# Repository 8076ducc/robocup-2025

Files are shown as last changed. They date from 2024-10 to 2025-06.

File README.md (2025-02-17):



# ducc. Robotics: RoboCupJunior Soccer 2025

This repository contains ducc's working files and source code for the 2025 RoboCupJunior Soccer Open and Soccer Lightweight competition.

## About

ducc is a six-man team comprising **Neo Hao Jun, Isaac Tan, Zhu Yunsong, Aidan Yeong, Faith Yang and Neo Jun Hao** from the **Hwa Chong Robotics Club** in Singapore.

## Technologies

This project was built with the following tools:

- Mechanical: Autodesk Fusion
- Electrical: KiCad 7.0
- Programming: PlatformIO

## Intellectual Property

### Copyright

© 2025, ducc. Robotics Competition Team.

While we have made every effort to abide by legal and ethical requirements when using works that we did not create, some may have been overlooked inadvertently. Please let us know and we will be happy to make the necessary arrangements.

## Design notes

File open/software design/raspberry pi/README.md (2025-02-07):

1. Get the dt-blob-bin file by running `sudo wget https://datasheets.raspberrypi.com/cmio/dt-blob-dualcam.bin -O /boot/dt-blob.bin` in the terminal.

2. Run `sudo nano /boot/firmware/config.txt` in the terminal, scroll down and add the following lines to the bottom of the file:
```
dtoverlay=imx708,cam0
dtoverlay=imx708,cam1
```

3. Run `libcamera-hello` in the terminal to determine if the cameras are detected.

4. Compile OpenCV from source; follow the guide [here](https://qengineering.eu/install-opencv-on-raspberry-64-os.html).

5. Install LCCV by following the instructions [here](https://github.com/8076ducc/lccv).

6. Create symbolic links by running the following commands in the terminal:
```bash
sudo ln -s /usr/local/include/opencv4/opencv2 /usr/local/include/opencv2
sudo ln -s /usr/include/libcamera/libcamera /usr/local/include/libcamera
```

7. Install wiringpi by following the guide [here](https://github.com/WiringPi/WiringPi).

8. In Geany, manage your build settings and configure it to compile via the following command:
```bash
sudo g++ -Wall -o "%e" "%f" -lopencv_core -lopencv_videoio -lopencv_highgui -lopencv_imgproc -lopencv_video -llccv -lwiringPi
```

9. Test Geany compilation by pressing the brown brick button in your desired file (e.g. `tracker.cpp`; don't compile in `threads.h` or some other header file) THEN run the code by clicking the airplane symbol. You may wish to use the function row keyboard shortcuts at your convenience.

10. Transfer the two files in the `systemctl` folder in this repository to the `/lib/systemd/system` folder on the Raspberry Pi.

11. Ensure "enable_debug_windows" in threads.h is set to false.

12. Individually check that the services are working using the following commands:
```bash
sudo systemctl start configure-gpio.service
sudo systemctl status configure-gpio.service
sudo systemctl stop configure-gpio.service

sudo systemctl start tracker.service
sudo systemctl status tracker.service
sudo systemctl stop tracker.service
```

12. Enable both services to run on startup using the following commands:
```bash
sudo systemctl enable configure-gpio.service
sudo systemctl enable tracker.service
```

13. Run `sudo systemctl disable NetworkManager-wait-online.service` in the terminal.

Other notes:
- DO NOT 千万不要 plug or unplug the camera module while power is still connected. Shut the RPi down and unplug all power cables before doing anything with the camera module.
- Placing everything in the Desktop is a personal decision I made so that it's more convenient for me to open files when I VNC into the RPi. You might want to pull the entire repository directly into the RPi (I highly recomend that); in which case you should change the directories to the executables in the `configure-gpio.service` and `tracker.service` files.

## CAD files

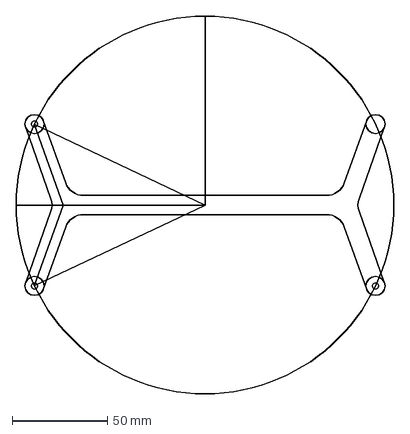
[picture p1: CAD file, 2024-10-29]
lightweight/lw handle.dxf
198.0 x 198.0 mm

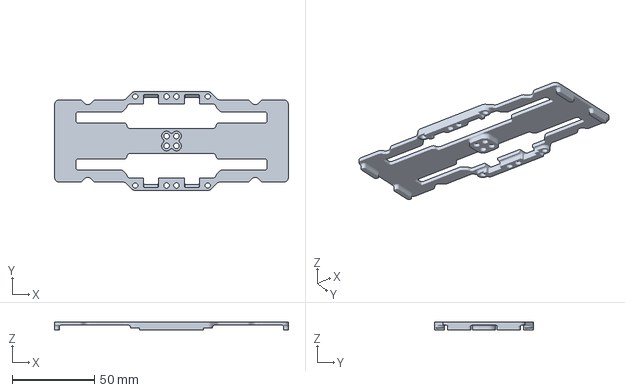
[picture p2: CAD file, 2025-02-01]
open/mechanical design/battery/driver cover (battery anti-short).3mf
142.0 x 60.0 x 5.00 mm

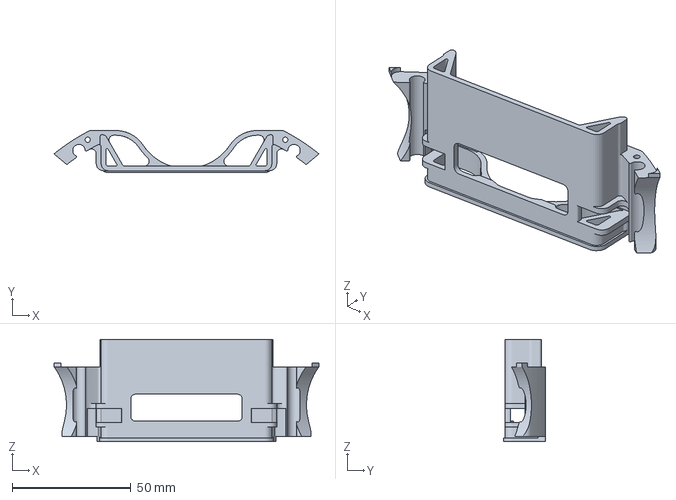
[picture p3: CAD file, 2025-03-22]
open/mechanical design/cover/layer 1/cover front (layer 1).3mf
111.8 x 17.7 x 43.2 mm

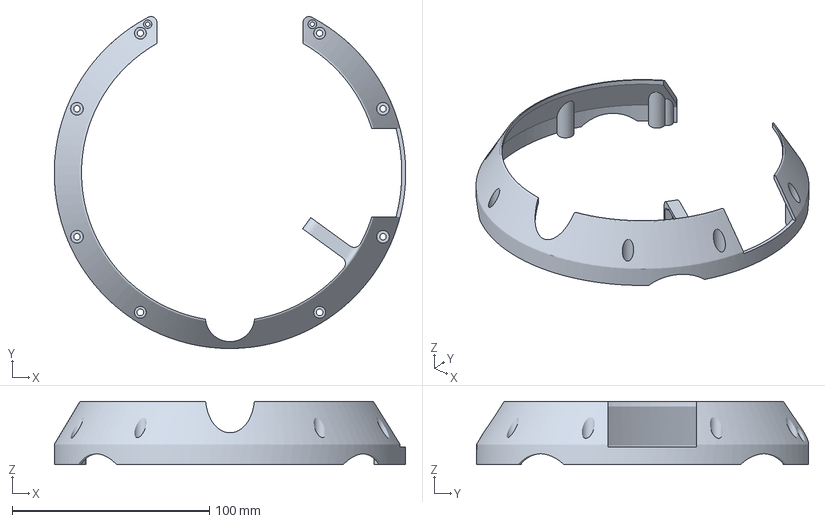
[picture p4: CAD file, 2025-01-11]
open/mechanical design/cover/layer 2/cover (layer 2).3mf
178.0 x 168.1 x 32.0 mm

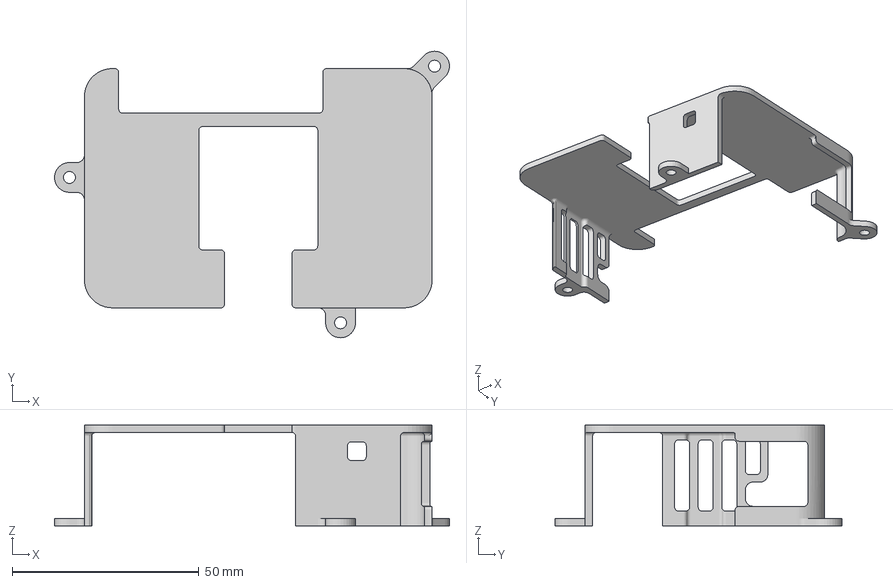
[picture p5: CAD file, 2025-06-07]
open/mechanical design/cover/layer 3/rpi cover.3mf
105.6 x 76.6 x 27.0 mm

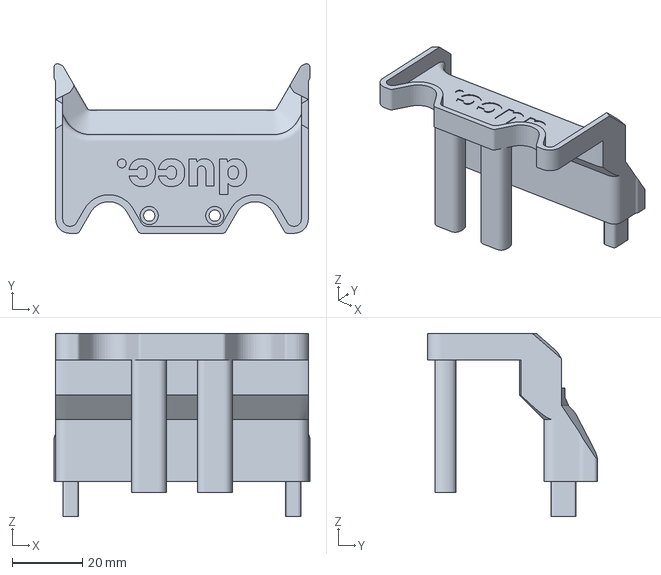
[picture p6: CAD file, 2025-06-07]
open/mechanical design/cover/servo/cover (servo).3mf
73.0 x 48.4 x 52.2 mm

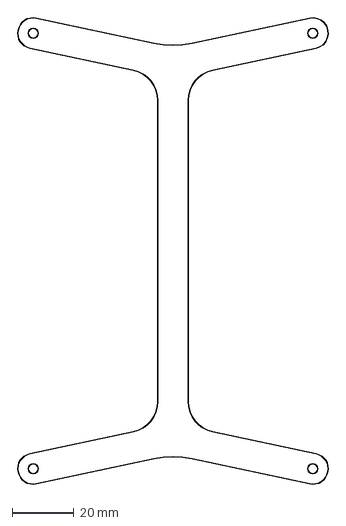
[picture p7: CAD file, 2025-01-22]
open/mechanical design/handle/handle.dxf
101.7 x 152.3 mm

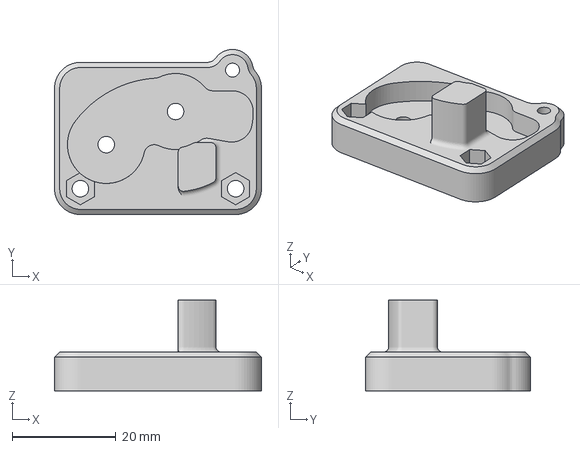
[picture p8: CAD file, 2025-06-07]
open/mechanical design/kicker/ratchet gear mount.3mf
40.0 x 31.9 x 17.5 mm

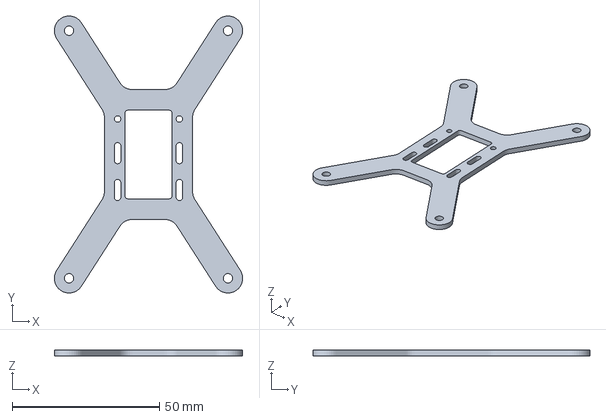
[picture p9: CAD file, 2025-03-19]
open/mechanical design/layer 4/layer 4 (new).3mf
64.0 x 94.2 x 2.00 mm

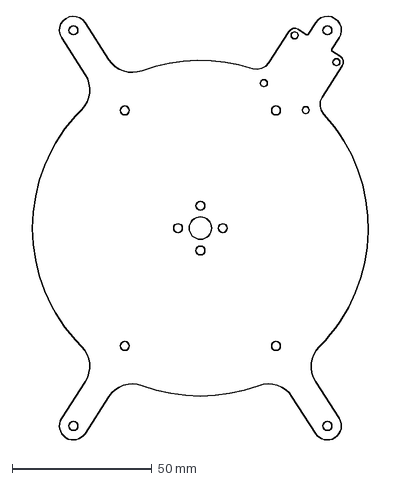
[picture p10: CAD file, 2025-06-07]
open/mechanical design/layer 5/layer 5 (no pin holes).dxf
131.8 x 152.2 mm

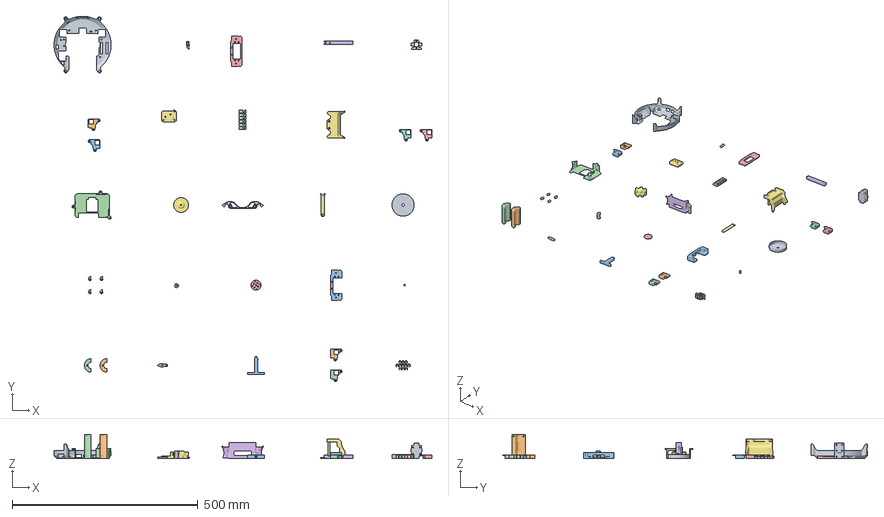
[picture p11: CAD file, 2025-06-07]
open/mechanical design/master.3mf
1018.0 x 984.3 x 65.0 mm
cover (layer 3)
buck cover left x 3
gear rack
buck cover right x 3
cover (servo)
rack
filament roller right
servo mount x 2
filament roller left
ratchet wheel
pawl x 4
wheel
ratchet
rpi cover
slide
ratchet gear mount
buck spacer x 6
cover front (layer 1)
m2.5 wrench
bearing spacer
mirror sawing plate
ratchet (new)
wire clip x 11

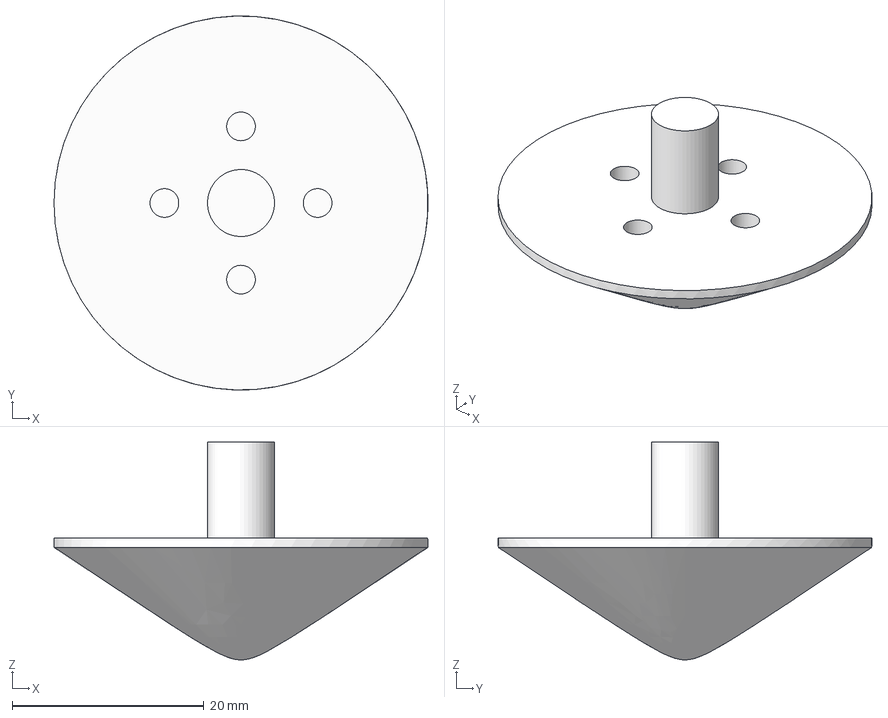
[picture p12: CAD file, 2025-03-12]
open/mechanical design/mirror/mirror with extrusion.step
39.1 x 39.0 x 22.7 mm

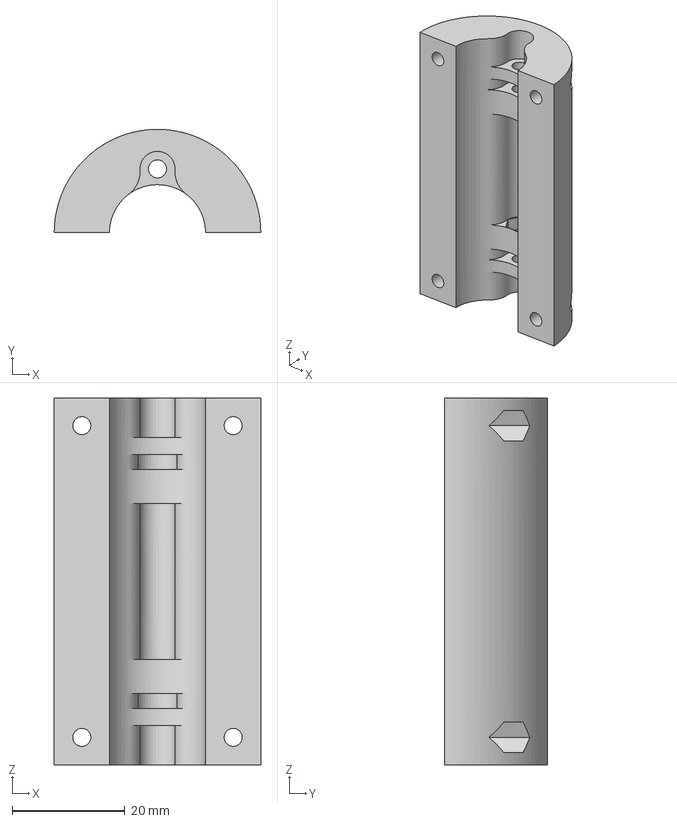
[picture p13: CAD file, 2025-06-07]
open/mechanical design/misc/filament roller left.3mf
36.6 x 18.3 x 65.0 mm

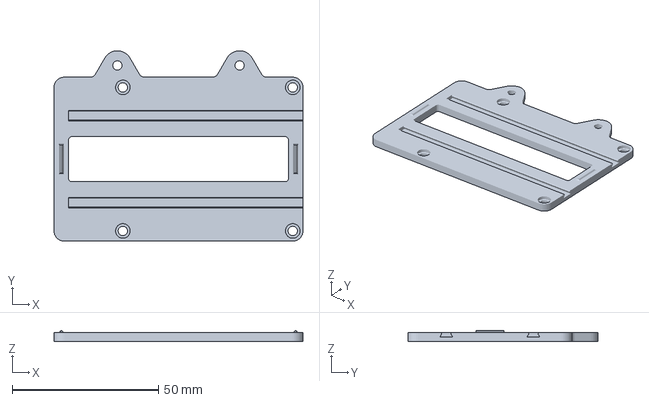
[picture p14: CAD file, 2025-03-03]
open/mechanical design/rpi & camera/base a/rpi mount base a upper.3mf
85.0 x 65.0 x 3.65 mm

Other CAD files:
open/mechanical design/rpi & camera/lens aligner.3mf
open/mechanical design/rpi & camera/nano b/rpi mount nano b.3mf
open/mechanical design/spinning kicker/left plate.3mf
open/mechanical design/wheel/4mm/wheel.3mf
open/mechanical design/battery/battery guide wall.3mf
open/mechanical design/cover/layer 1/cover back (layer 1).3mf
open/mechanical design/cover/layer 1/cover left (layer 1).3mf
open/mechanical design/cover/layer 1/cover right (layer 1).3mf
open/mechanical design/cover/layer 1/old/cover back (layer 1).stl
open/mechanical design/cover/layer 1/old/cover front left (layer 1) - old.stl
open/mechanical design/cover/layer 1/old/cover front left (layer 1).stl
open/mechanical design/cover/layer 1/old/cover front right (layer 1).stl
open/mechanical design/cover/layer 1/old/cover left (layer 1).stl
open/mechanical design/cover/layer 1/old/cover right (layer 1).stl
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

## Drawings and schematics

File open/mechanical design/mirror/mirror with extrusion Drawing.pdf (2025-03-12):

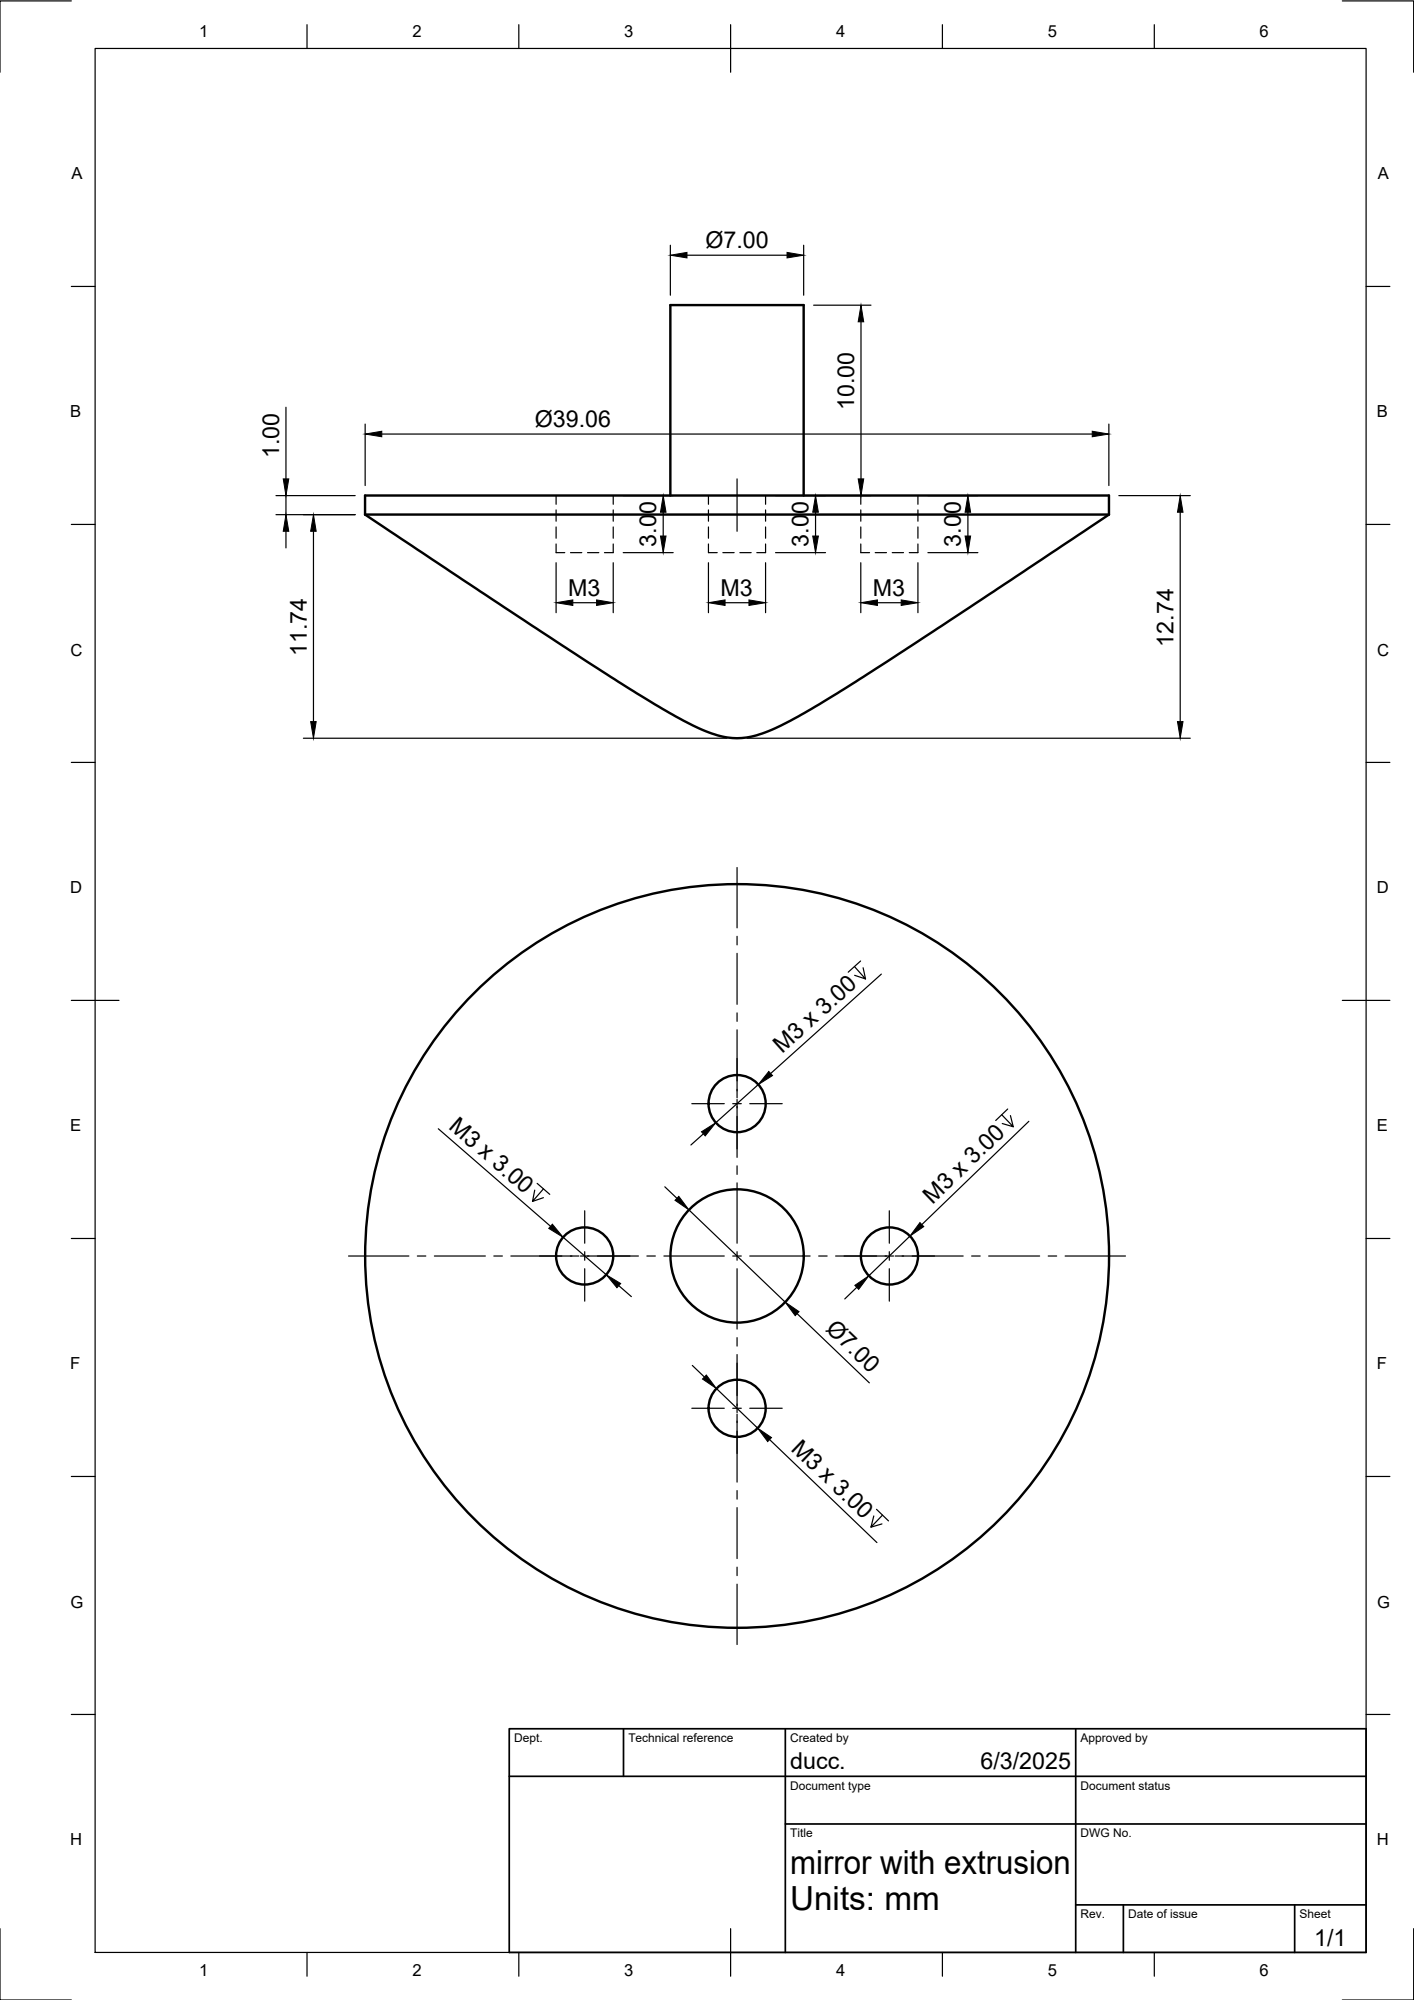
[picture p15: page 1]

Dept. | Technical reference | Created by ducc. 6/3/2025 | Approved by

Document type | Document status

Title mirror with extrusion Units: mm | DWG No.

Rev. | Date of issue | Sheet 1/1

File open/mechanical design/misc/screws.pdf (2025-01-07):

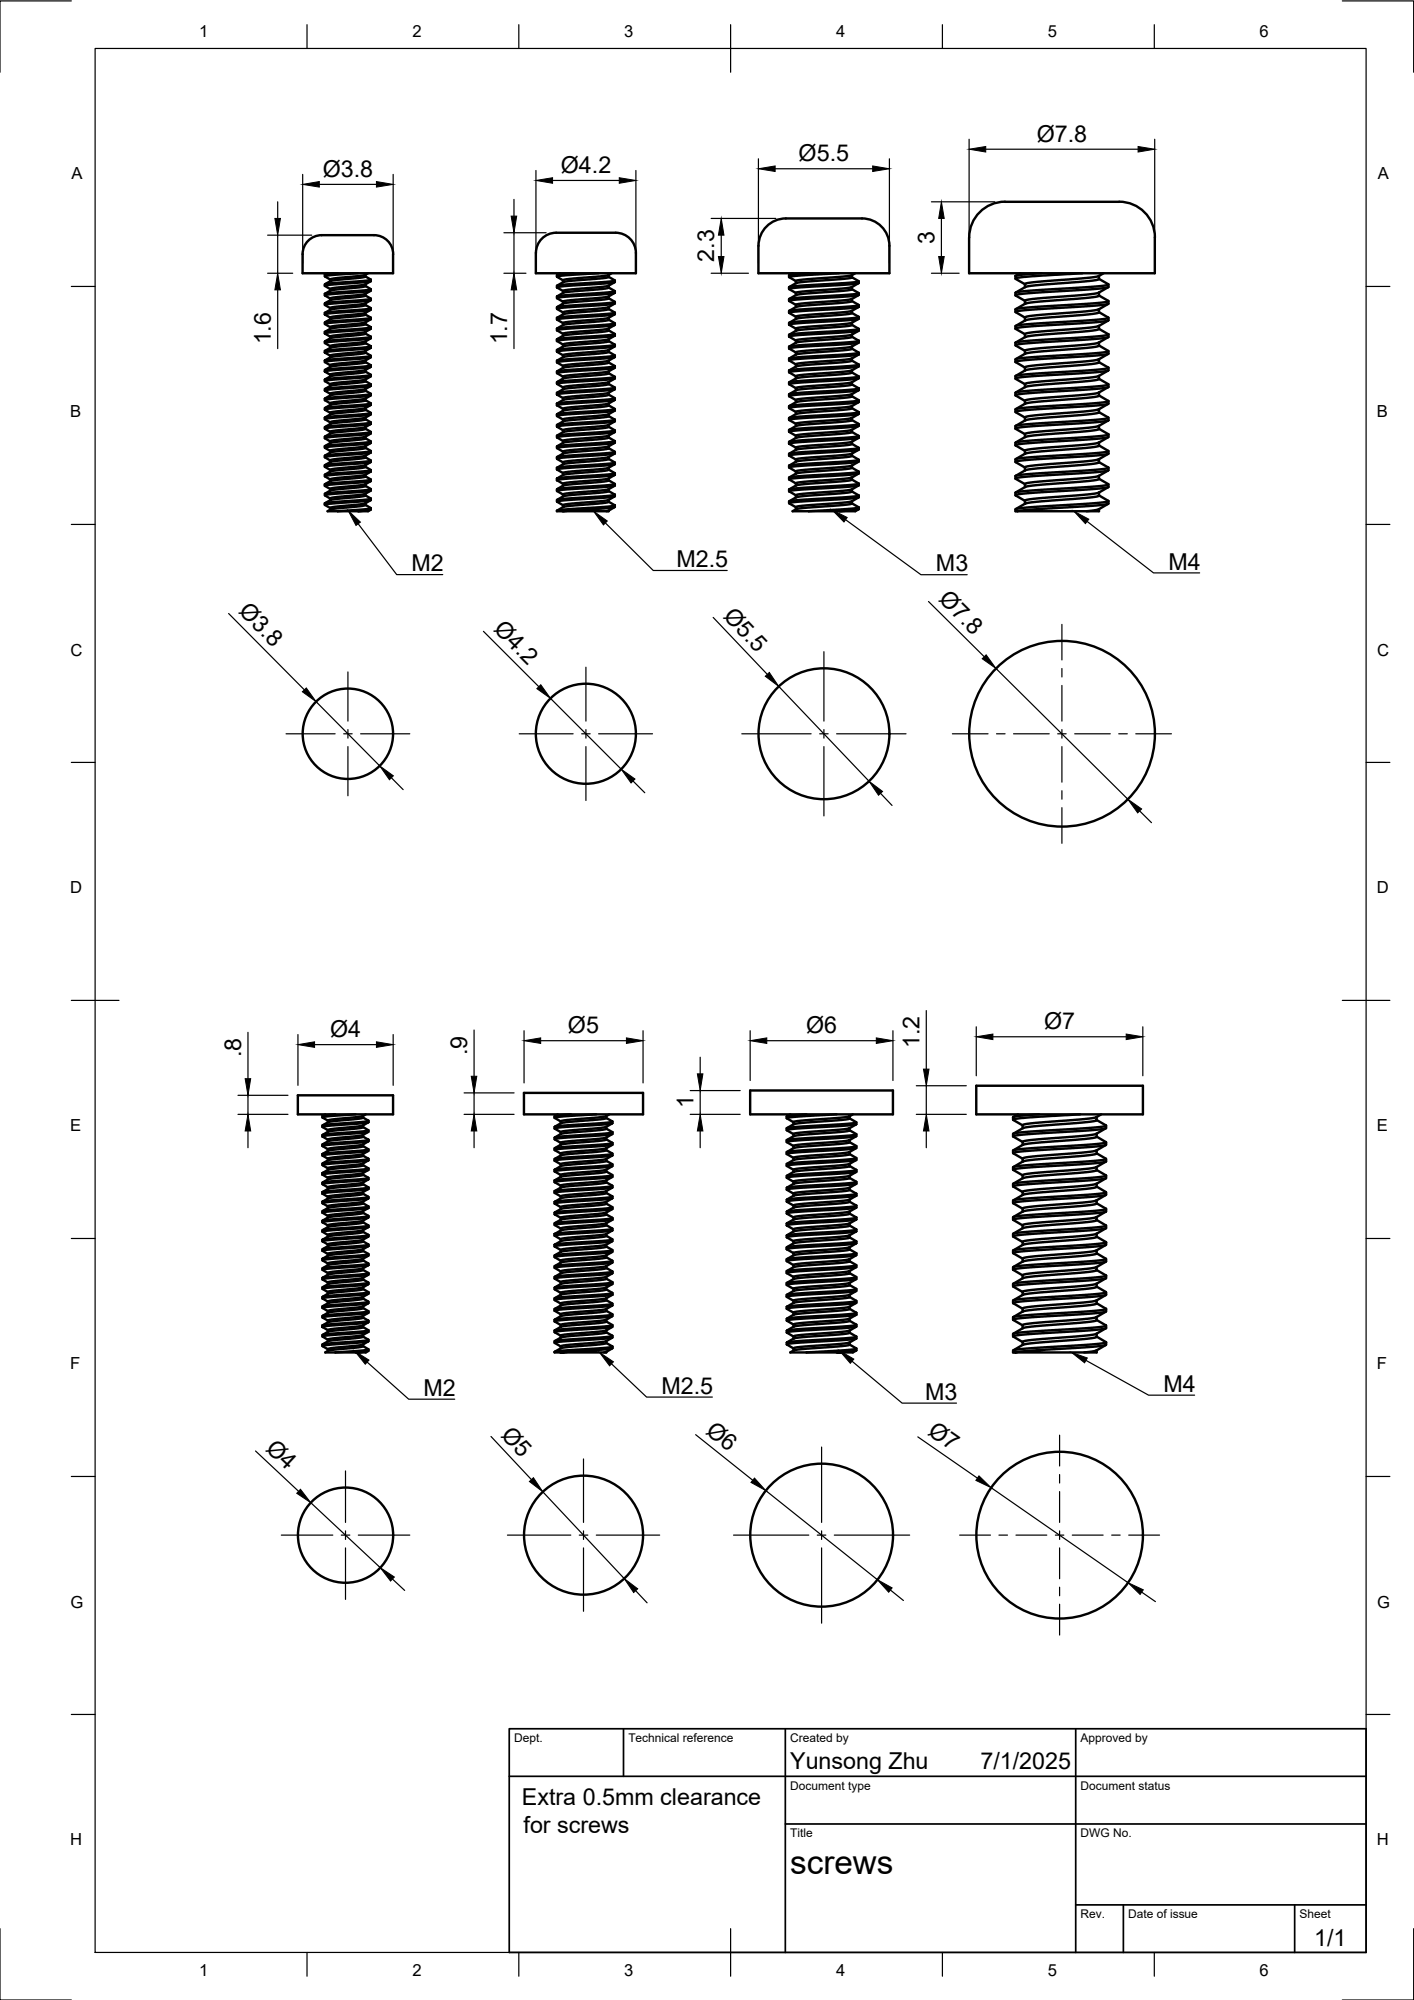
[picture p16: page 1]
for screws .8

Dept. | Technical reference | Created by Yunsong Zhu 7/1/2025 | Approved by

Extra 0.5mm clearance | | Document type | Document status

Title screws | DWG No.

Rev. | Date of issue | Sheet 1/1

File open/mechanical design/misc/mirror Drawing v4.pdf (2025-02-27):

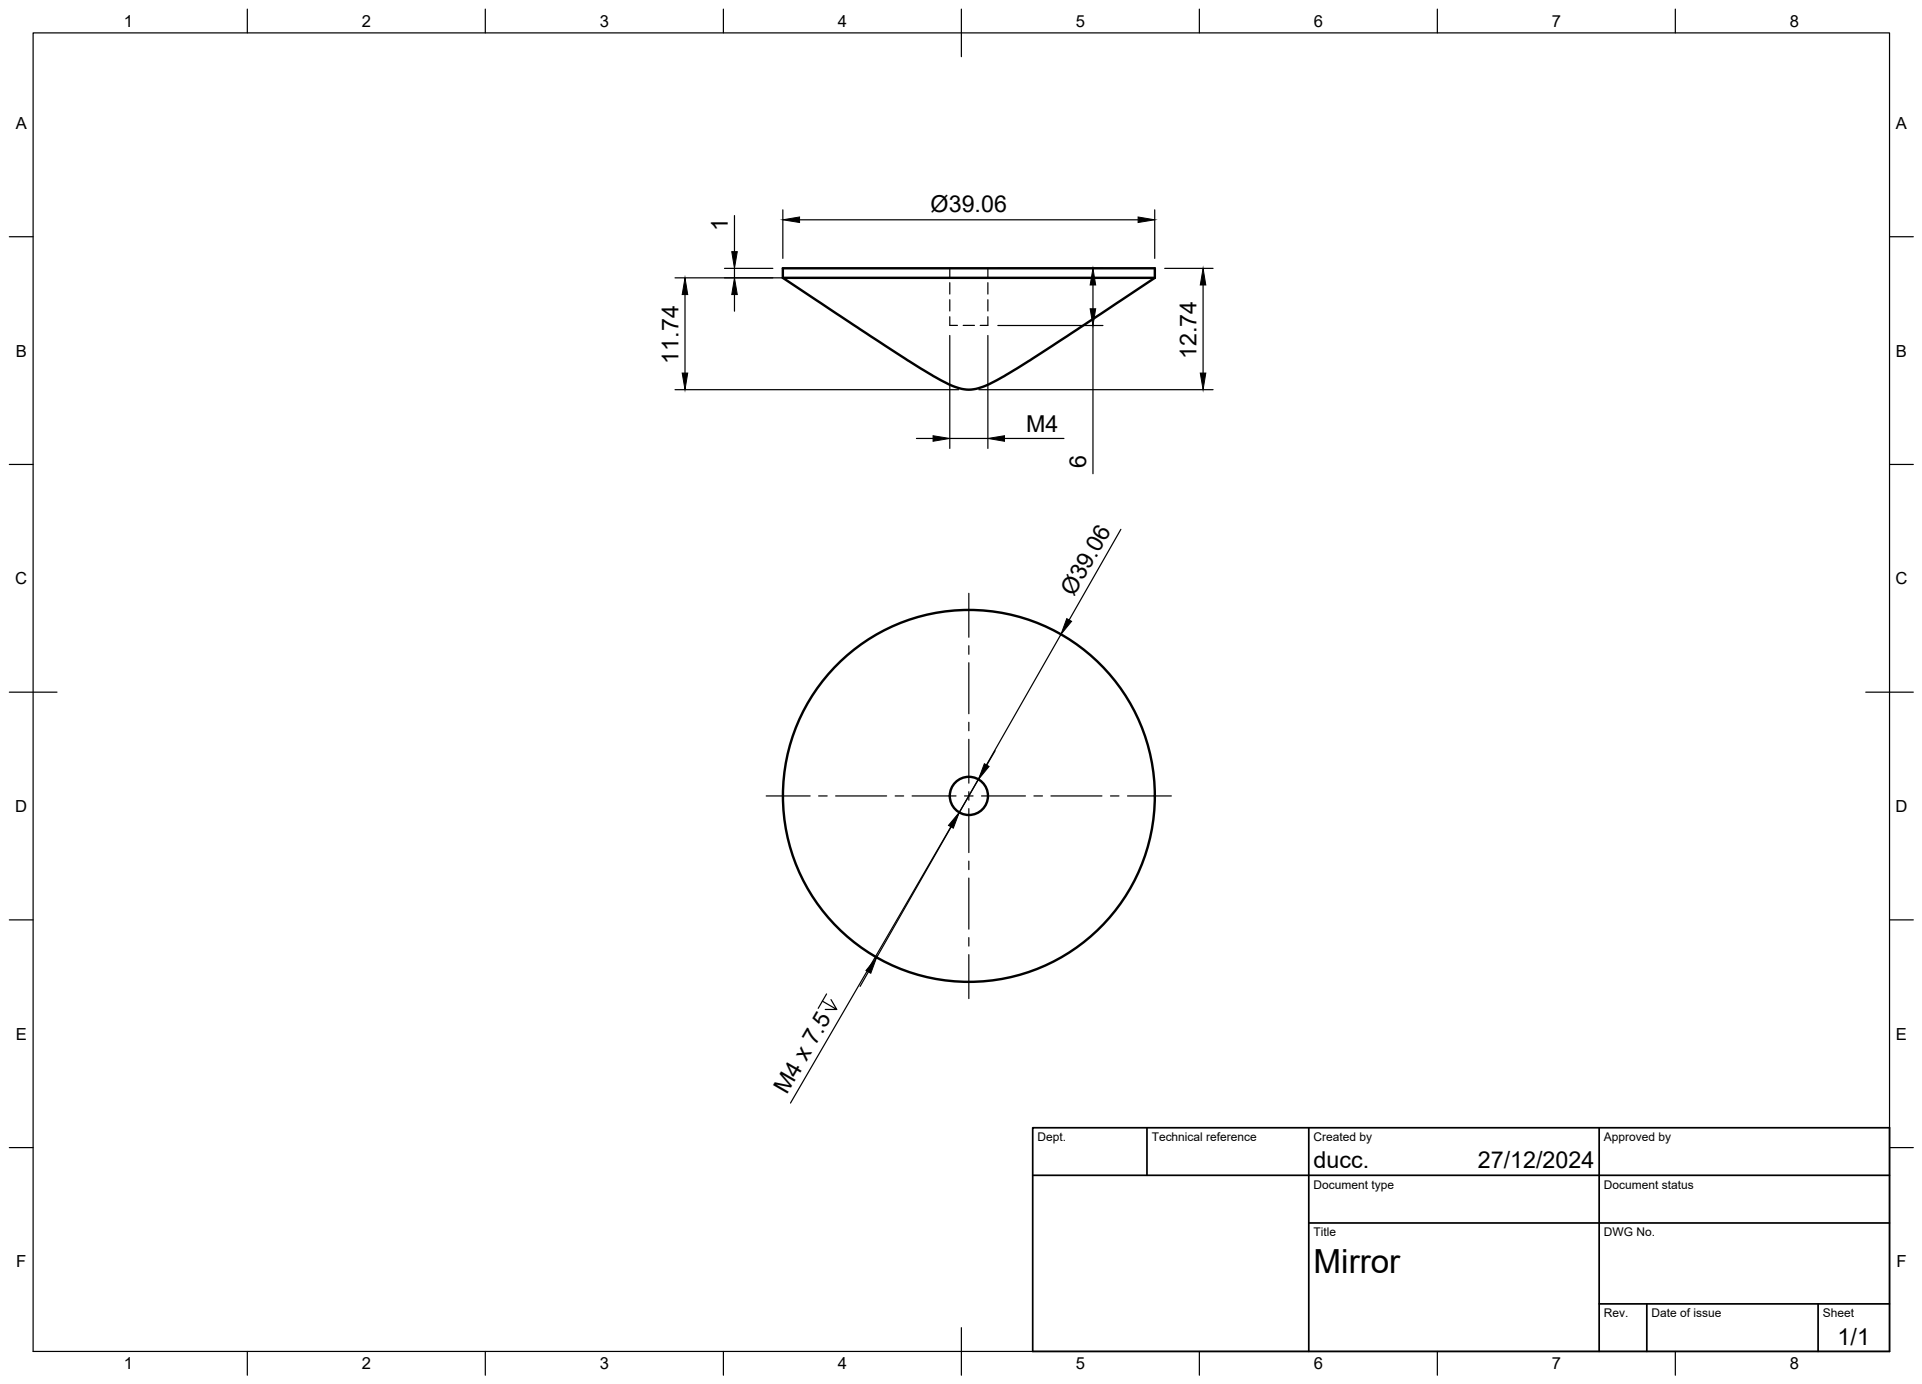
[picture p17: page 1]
Title; DWG No.; Rev.; Date of issue; Sheet

Dept. | Technical reference | Created by ducc. 27/12/2024 | Approved by

Document type | Document status

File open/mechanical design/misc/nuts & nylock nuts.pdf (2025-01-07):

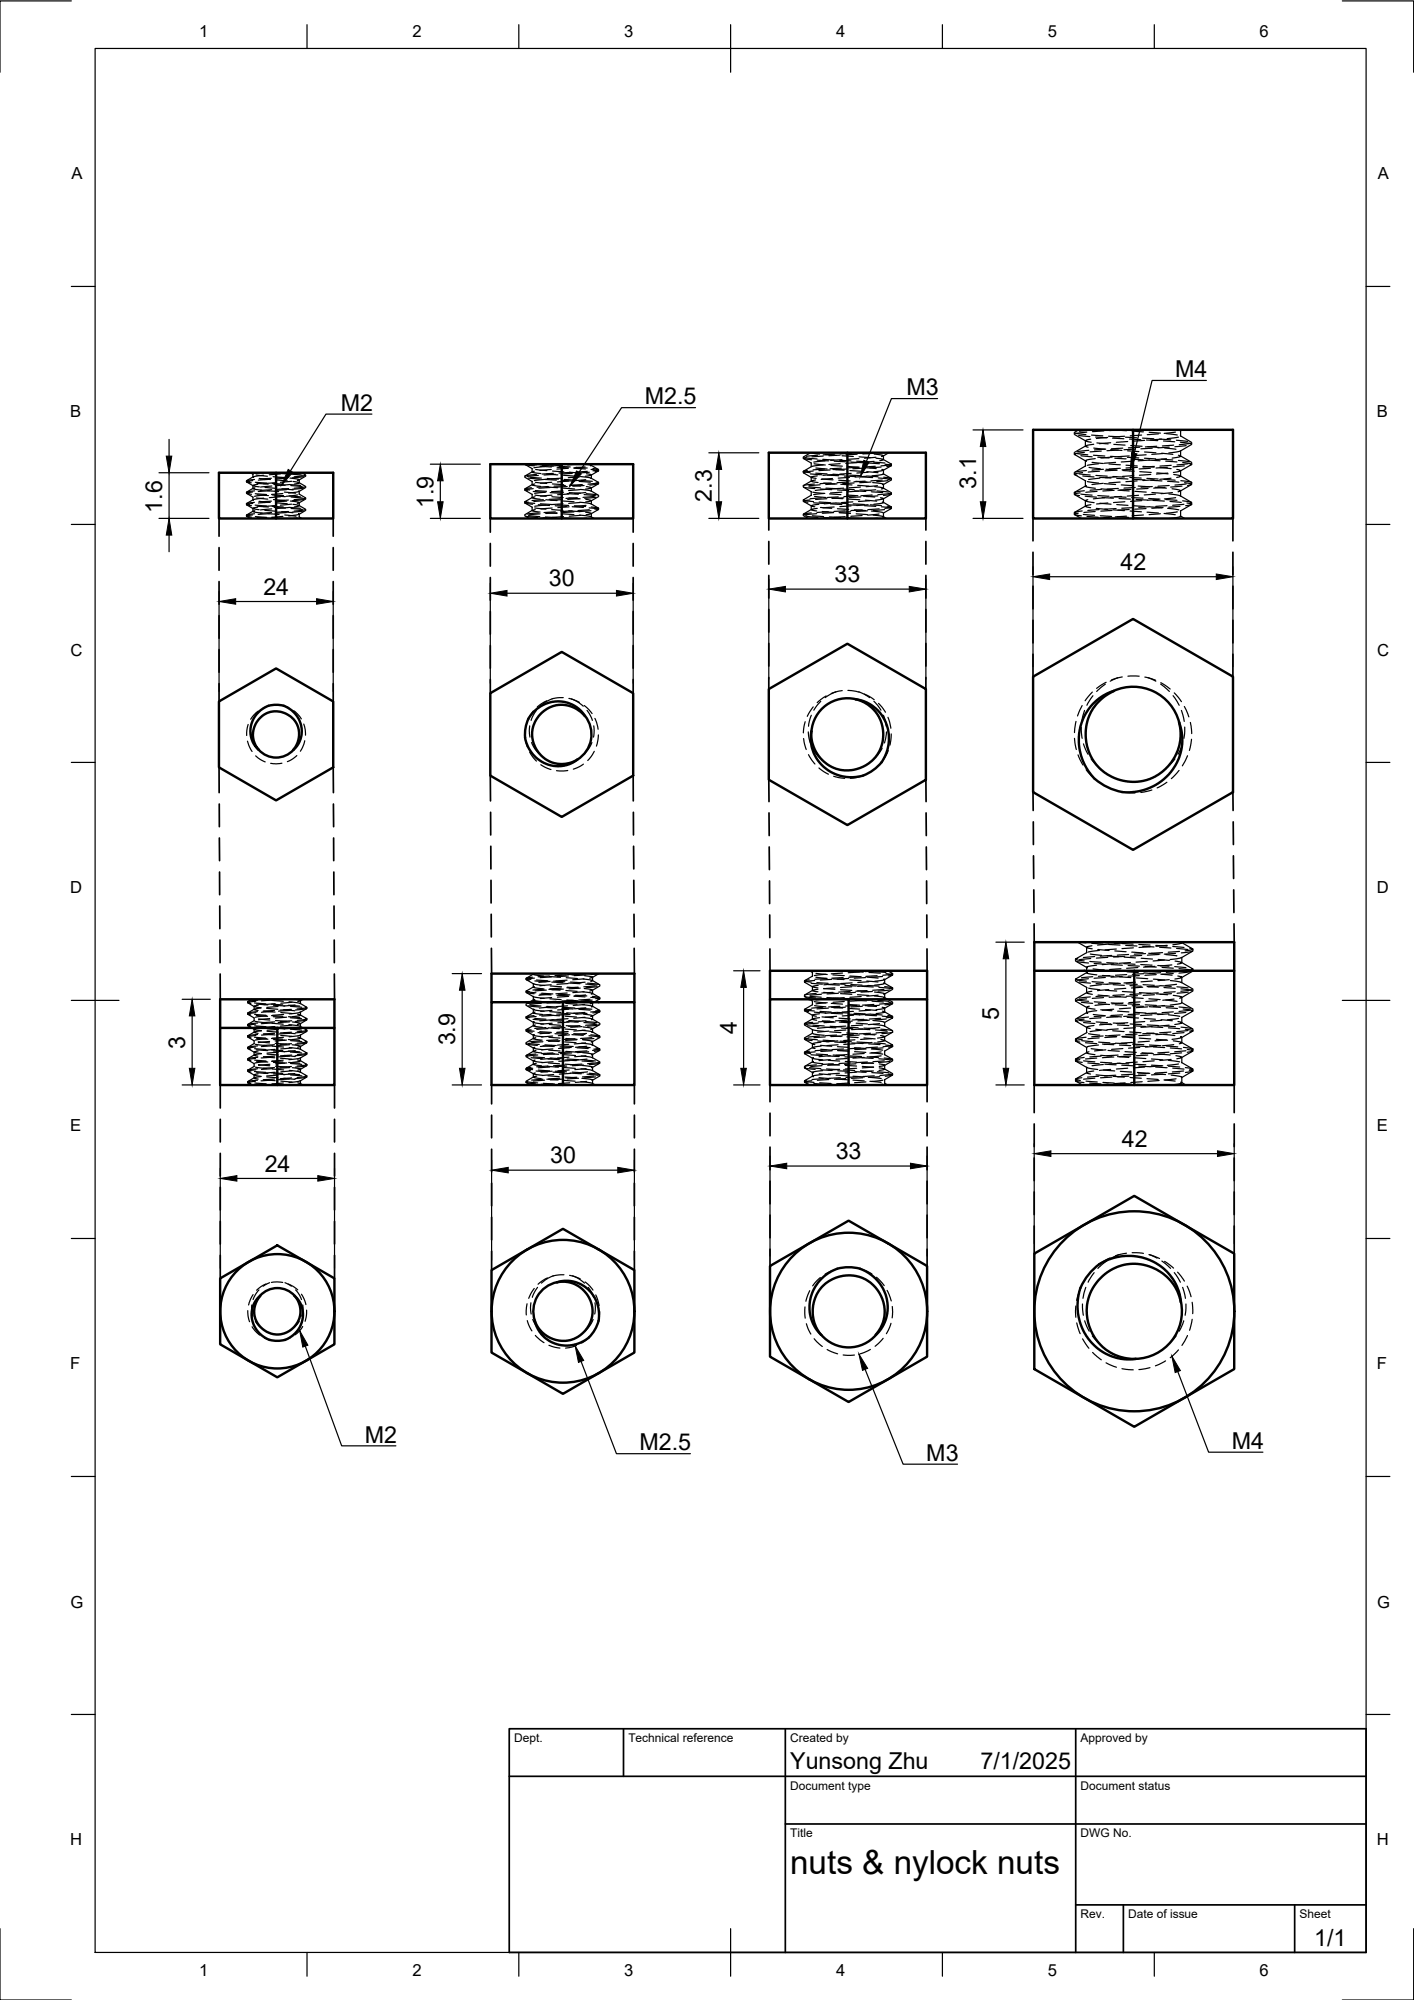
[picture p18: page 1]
Yunsong Zhu 1.6

Dept. | Technical reference | Created by 7/1/2025 | Approved by

Document type | Document status

Title nuts & nylock nuts | DWG No.

Rev. | Date of issue | Sheet 1/1

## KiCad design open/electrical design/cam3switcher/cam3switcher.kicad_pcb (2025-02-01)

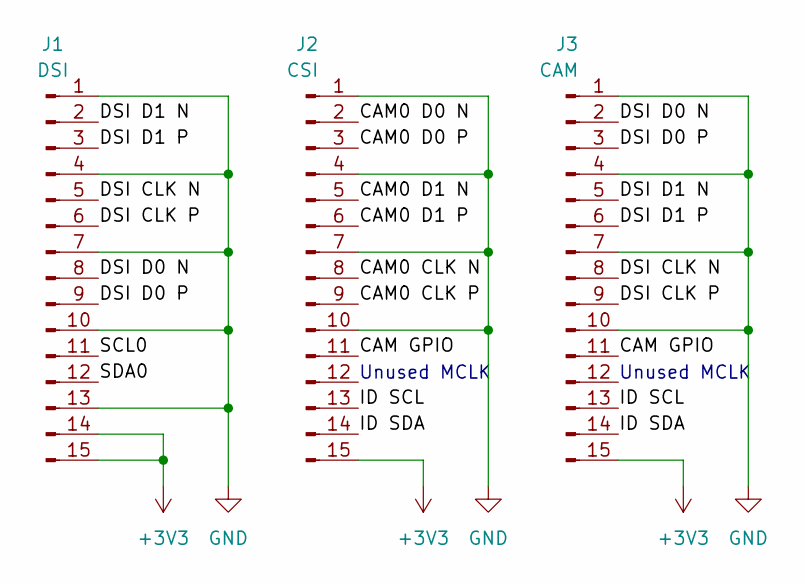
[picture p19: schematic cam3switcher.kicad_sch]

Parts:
J1: DSI; TE_1-84952-5_1x15-1MP_P1.0mm_Horizontal
J2: CSI; TE_1-84952-5_1x15-1MP_P1.0mm_Horizontal
J3: CAM; TE_1-84952-5_1x15-1MP_P1.0mm_Horizontal

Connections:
+3V3: J1.14, J1.15, J2.15, J3.15
/CAM0 CLK N: J2.8
/CAM0 CLK P: J2.9
/CAM0 D0 N: J2.2
/CAM0 D0 P: J2.3
/CAM0 D1 N: J2.5
/CAM0 D1 P: J2.6
/CAM GPIO: J2.11, J3.11
/DSI CLK N: J1.5, J3.8
/DSI CLK P: J1.6, J3.9
/DSI D0 N: J1.8, J3.2
/DSI D0 P: J1.9, J3.3
/DSI D1 N: J1.2, J3.5
/DSI D1 P: J1.3, J3.6
/ID SCL: J2.13, J3.13
/ID SDA: J2.14, J3.14
/SCL0: J1.11
/SDA0: J1.12
GND: J1.1, J1.4, J1.7, J1.10, J1.13, J2.1, J2.4, J2.7, J2.10, J3.1, J3.4, J3.7, J3.10

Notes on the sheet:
Unused MCLK

Board: 2 copper layers, 3 parts (0 on the bottom side), 11 nets, no tracks yet.

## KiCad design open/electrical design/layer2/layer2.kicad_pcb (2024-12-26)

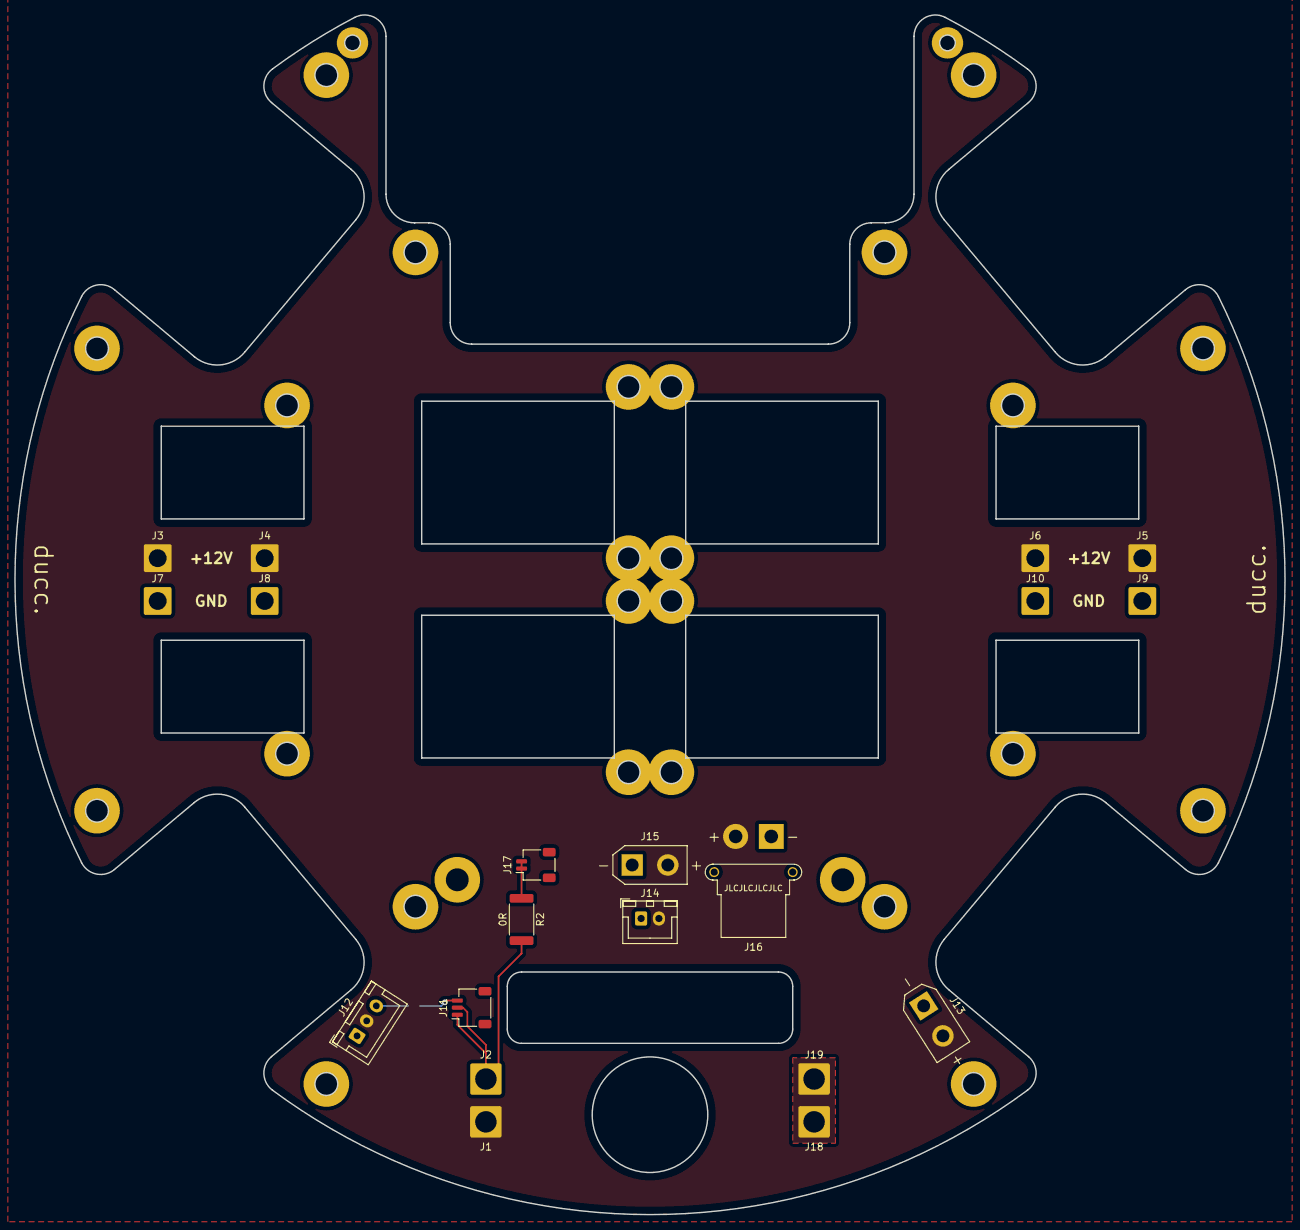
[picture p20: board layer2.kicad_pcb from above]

Board: 2 copper layers, 178.0 x 168.1 mm, 49 parts (1 on the bottom side), 6 nets.

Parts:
H1, H2, H3, H4, H5, H6, H7, H8, H9, H10, H11, H12, H13, H14, H15, H16, H17, H18, H19, H20, H21, H22, H23, H24, H25, H26: MountingHole; MountingHole_3.2mm_M3_Pad
H33, H34: MountingHole; MountingHole_2.2mm_M2_Pad
J1, J2, J18, J19: Conn_01x01_Female; SolderWire-2.5sqmm_1x01_D2.4mm_OD4.4mm
J3, J4, J5, J6, J7, J8, J9, J10: Conn_01x01_Female; SolderWire-2sqmm_1x01_D2mm_OD3.9mm
J11: SH1.0 3P; JST_SH_SM03B-SRSS-TB_1x03-1MP_P1.00mm_Horizontal
J12: XH2.54 3P; JST_XH_B3B-XH-A_1x03_P2.50mm_Vertical
J13, J15: XT30UPB-F; AMASS_XT30UPB-F_1x02_P5.0mm_Vertical
J14: XH2.54 2P; JST_XH_B2B-XH-A_1x02_P2.50mm_Vertical
J16: XT30PW-F; AMASS_XT30PW-F_1x02_P2.50mm_Horizontal
J17: SH1.0 2P; JST_SH_SM02B-SRSS-TB_1x02-1MP_P1.00mm_Horizontal
R1: 10k; R_0603_1608Metric
R2: 0R; R_2512_6332Metric

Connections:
+3V3: J11.3, R1.2
+12V: J1.1, J3.1, J4.1, J5.1, J6.1, J12.2, J13.2, J14.2, J15.2, J16.2
/BATT: J18.1, J19.1
GND: J2.1, J7.1, J8.1, J9.1, J10.1, J11.1, J11.2, J12.1, J13.1, J14.1, J15.1, J16.1, R2.2
unnamed: J12.3, R1.1
unnamed: J17.1, J17.2, R2.1

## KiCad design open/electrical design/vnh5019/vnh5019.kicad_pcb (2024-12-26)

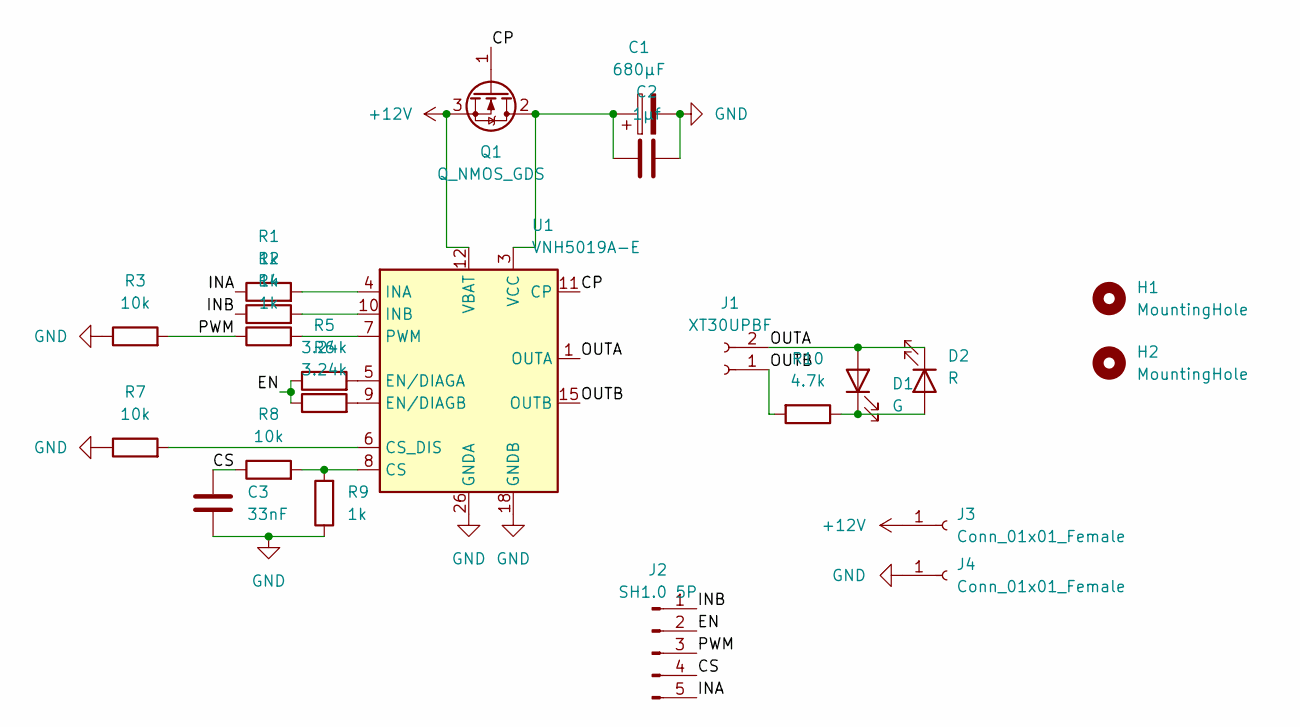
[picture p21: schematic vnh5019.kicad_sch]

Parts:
C1: 680µF; CP_Radial_D8.0mm_P3.50mm
C2: 1µf; C_0603_1608Metric
C3: 33nF; C_0603_1608Metric
D1: G; D_0603_1608Metric
D2: R; D_0603_1608Metric
H1, H2: MountingHole; MountingHole_3.2mm_M3_Pad
J1: XT30UPBF; AMASS_XT30UPB-F_1x02_P5.0mm_Vertical
J2: SH1.0 5P; JST_SH_SM05B-SRSS-TB_1x05-1MP_P1.00mm_Horizontal
J3, J4: Conn_01x01_Female; SolderWirePad_1x01_SMD_5x10mm
Q1: Q_NMOS_GDS; TO-252-2
R1, R2, R4, R9: 1k; R_0603_1608Metric
R3, R7, R8: 10k; R_0603_1608Metric
R5, R6: 3.24k; R_0603_1608Metric
R10: 4.7k; R_0603_1608Metric
U1: VNH5019A-E; ST_MultiPowerSO-30

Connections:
+12V: J3.1, Q1.3 (S), U1.12 (VBAT)
/CP: Q1.1 (G), U1.11 (CP)
/CS: C3.1, J2.4, R8.1
/EN: J2.2, R5.1, R6.1
/INA: J2.5, R1.1
/INB: J2.1, R2.1
/OUTA: D1.2 (A), D2.1 (K), J1.2, U1.1 (OUTA), U1.25 (OUTA), U1.30 (OUTA), U1.33 (OUTA)
/OUTB: J1.1, R10.2, U1.15 (OUTB), U1.16 (OUTB), U1.21 (OUTB), U1.32 (OUTB)
/PWM: J2.3, R3.2, R4.1
GND: C1.2, C2.2, C3.2, J4.1, R3.1, R7.1, R9.1, U1.18 (GNDB), U1.19 (GNDB), U1.20 (GNDB), U1.26 (GNDA), U1.27 (GNDA), U1.28 (GNDA)
unnamed: D1.1 (K), D2.2 (A), R10.1
unnamed: C1.1, C2.1, Q1.2 (D), U1.3 (VCC), U1.13 (VCC), U1.23 (VCC), U1.31 (VCC)
unnamed: R8.2, R9.2, U1.8 (CS)
unnamed: R7.2, U1.6 (CS_DIS)
unnamed: R5.2, U1.5 (EN/DIAGA)
unnamed: R6.2, U1.9 (EN/DIAGB)
unnamed: R1.2, U1.4 (INA)
unnamed: R2.2, U1.10 (INB)
unnamed: R4.2, U1.7 (PWM)

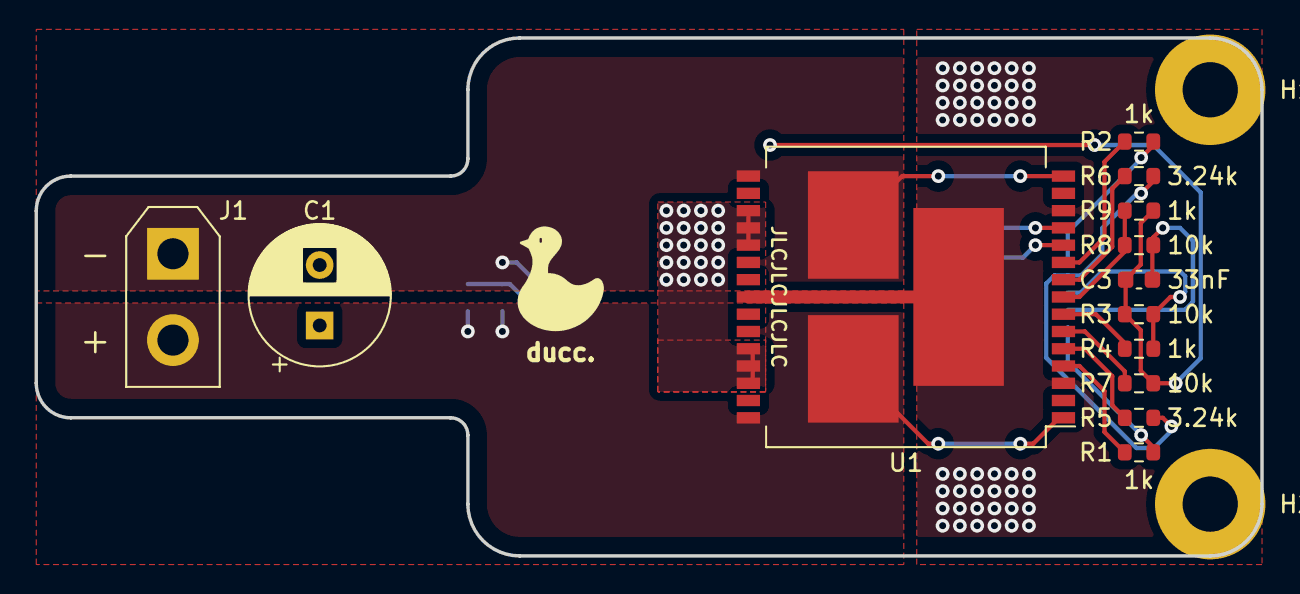
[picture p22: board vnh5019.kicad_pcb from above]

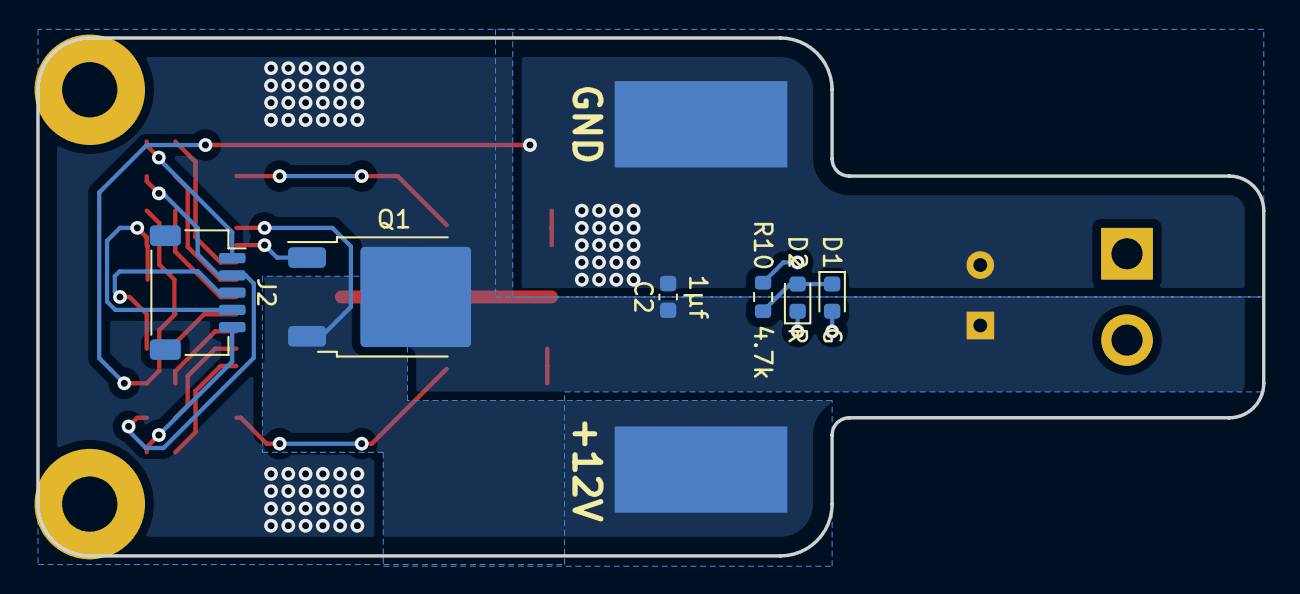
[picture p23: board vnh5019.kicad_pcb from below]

Board: 2 copper layers, 71.0 x 30.0 mm, 23 parts (8 on the bottom side), 19 nets.

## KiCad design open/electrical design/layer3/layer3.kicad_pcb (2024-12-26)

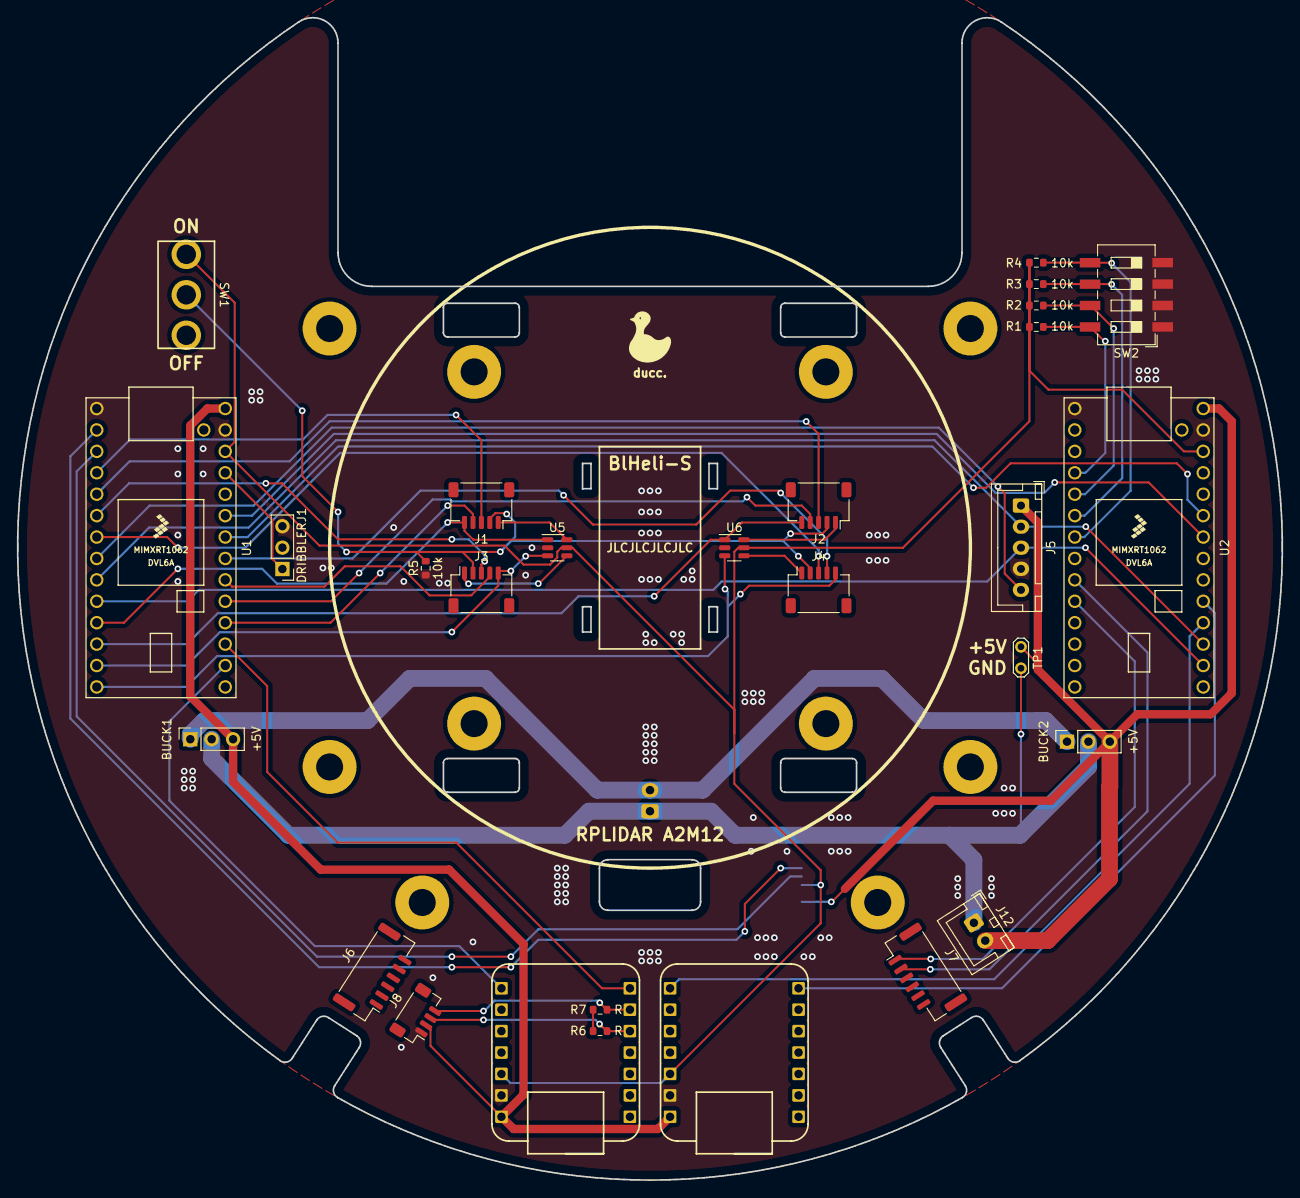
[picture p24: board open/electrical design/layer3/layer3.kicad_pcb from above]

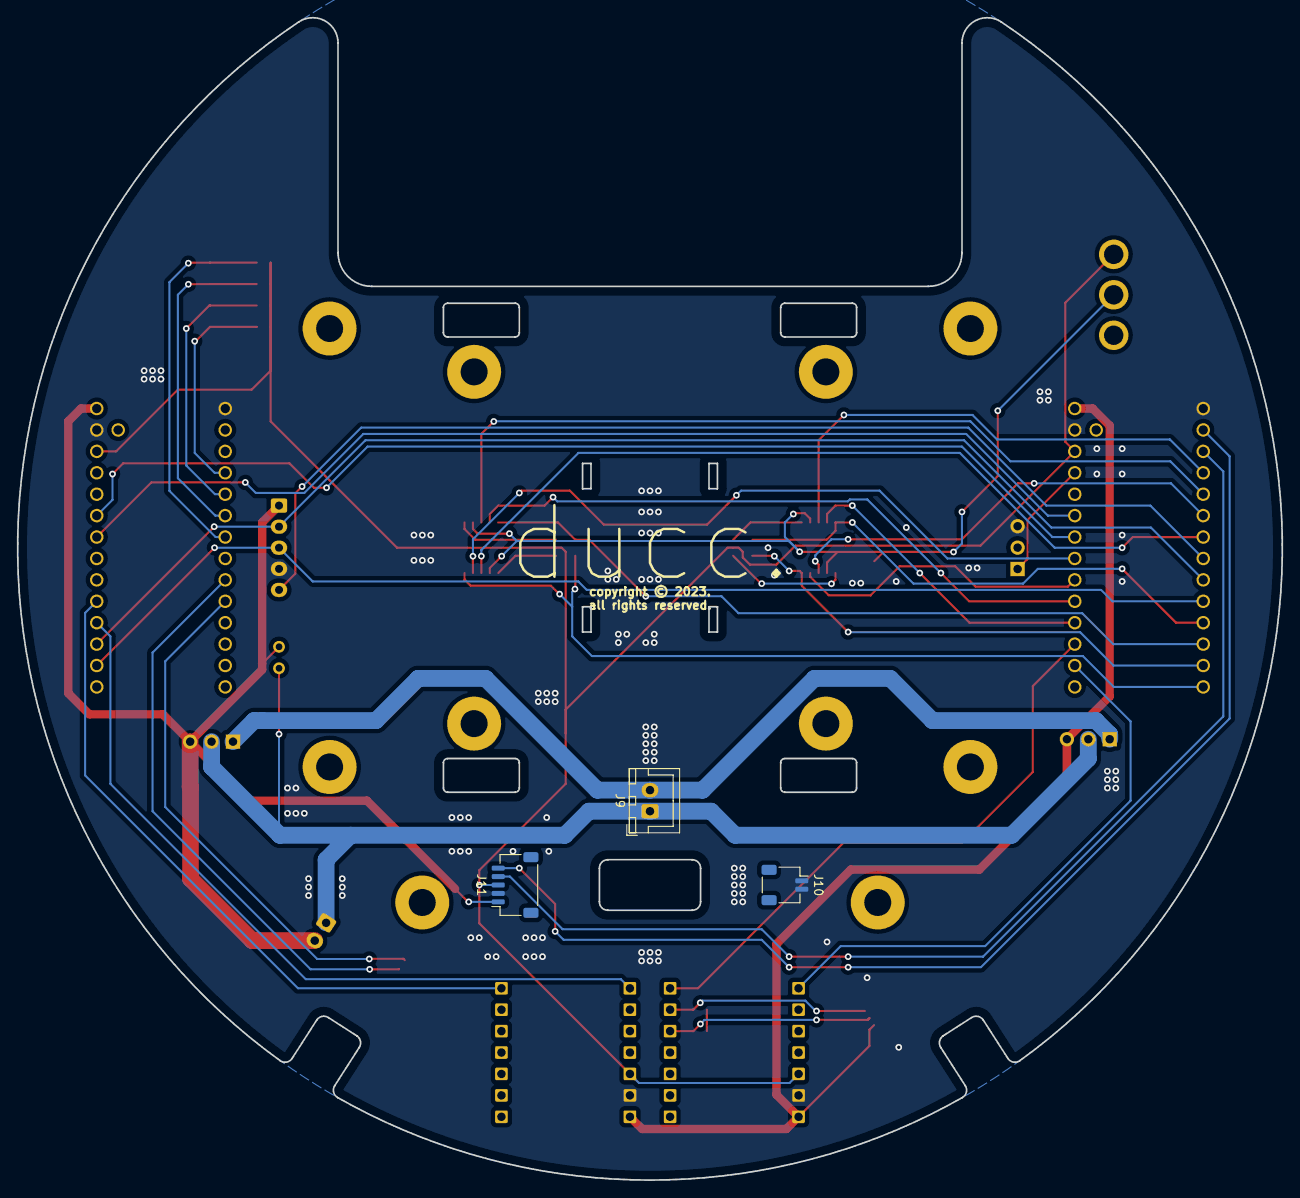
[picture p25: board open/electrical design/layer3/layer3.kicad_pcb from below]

Board: 2 copper layers, 150.0 x 137.9 mm, 41 parts (3 on the bottom side), 45 nets.

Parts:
BUCK1, BUCK2: +5V; TPS5430 Board
DRIBBLERJ1: Conn_01x03_Male; PinHeader_1x03_P2.54mm_Vertical
H1, H2, H3, H4, H5, H6, H7, H8, H9, H10: MountingHole; MountingHole_3.2mm_M3_Pad
J1, J2, J3, J4, J11: SH1.0 5P; JST_SH_SM05B-SRSS-TB_1x05-1MP_P1.00mm_Horizontal
J5: XH2.54 5P; JST_XH_B5B-XH-A_1x05_P2.50mm_Vertical
J6: CAMERA1; JST_GH_BM06B-GHS-TBT_1x06-1MP_P1.25mm_Vertical
J7: CAMERA2; JST_GH_BM06B-GHS-TBT_1x06-1MP_P1.25mm_Vertical
J8: COMPASS; JST_SH_BM04B-SRSS-TB_1x04-1MP_P1.00mm_Vertical
J9, J12: XH2.54 2P; JST_XH_B2B-XH-A_1x02_P2.50mm_Vertical
J10: SH1.0 2P; JST_SH_SM02B-SRSS-TB_1x02-1MP_P1.00mm_Horizontal
R1, R2, R3, R4, R5: 10k; R_0603_1608Metric
R6, R7: R; R_0603_1608Metric
SW1: SW_SPDT; SWITCH_SPDT_PTH_12.7X6.7MM
SW2: SW_DIP_x04; SW_DIP_SPSTx04_Slide_6.7x11.72mm_W8.61mm_P2.54mm_LowProfile
TP1: TestPoint_2Pole; TestPoint_2Pads_Pitch2.54mm_Drill0.8mm
U1, U2: TEENSY 4.0; Teensy40
U3, U4: MOUDLE-SEEEDUINO-XIAO-ESP32C3; xiao-esp32c3
U5, U6: 74LVC2G04; SOT-23-6

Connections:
+3V3: J11.3, R1.1, R2.1, R3.1, R4.1, SW1.1 (A), U1.3.3V_2, U2.3.3V_2, U3.12 (3V3), U4.12 (3V3), U5.5 (VCC), U6.5 (VCC)
+5V: BUCK1.3, BUCK2.3, J5.1, J8.2, J11.1, J12.2, TP1.1, U1.VIN, U2.VIN, U3.14 (5V), U4.14 (5V)
+12V: BUCK1.1, BUCK2.1, J9.2
/BTRX: U2.17, U4.7 (PB08_A6_D6_TX)
/BTTX: U2.16, U4.8 (PB09_A7_D7_RX)
/CAM1RX: J6.1, U2.1
/CAM1TX: J6.2, U2.0
/CAM2RX: J7.1, U2.8
/CAM2TX: J7.2, U2.7
/DRIBBLERPWM: DRIBBLERJ1.1, U1.23
/EN: J1.2, J2.2, J3.2, J4.2, R5.2, SW1.2 (B)
/IMURX: U1.14, U3.8 (PB09_A7_D7_RX)
/IMUSCL: J8.4, R7.1, U3.6 (PA9_A5_D5_SCL)
/IMUSDA: J8.3, R6.1, U3.5 (PA8_A4_D4_SDA)
/IMUTX: U1.15, U3.7 (PB08_A6_D6_TX)
/L1RX: J11.4, U1.1
/L1TX: J11.5, U1.0
/LIDARPWM: J5.5, U1.6
/LIDARRX: J5.3, U1.8, U2.14
/LIDARTX: J5.2, U1.7, U2.15
/M1CS: J1.4, U1.16
/M1INA: J1.5, U1.9, U5.1
/M1INB: J1.1, U5.6
/M1PWM: J1.3, U1.2
/M2CS: J2.4, U1.17
/M2INA: J2.5, U1.10, U6.1
/M2INB: J2.1, U6.6
/M2PWM: J2.3, U1.3
/M3CS: J3.4, U1.18
/M3INA: J3.5, U1.11, U5.3
/M3INB: J3.1, U5.4
/M3PWM: J3.3, U1.4
/M4CS: J4.4, U1.19
/M4INA: J4.5, U1.12, U6.3
/M4INB: J4.1, U6.4
/M4PWM: J4.3, U1.5
/RX: U1.20, U2.21
/STRAT1: R1.2, SW2.8, U2.2
/STRAT2: R2.2, SW2.7, U2.3
/STRAT3: R3.2, SW2.6, U2.4
/STRAT4: R4.2, SW2.5, U2.5
/TX: U1.21, U2.20
GNDD: DRIBBLERJ1.3, J5.4, J8.1, J10.1, J10.2, J11.2, R5.1, SW2.1, SW2.2, SW2.3, SW2.4, U1.G1, U1.G3, U2.G1, U2.G3, U3.13 (GND), U4.13 (GND), U5.2 (GND), U6.2 (GND)
GNDPWR: BUCK1.2, BUCK2.2, J9.1, J12.1, TP1.2
unnamed: R6.2, R7.2

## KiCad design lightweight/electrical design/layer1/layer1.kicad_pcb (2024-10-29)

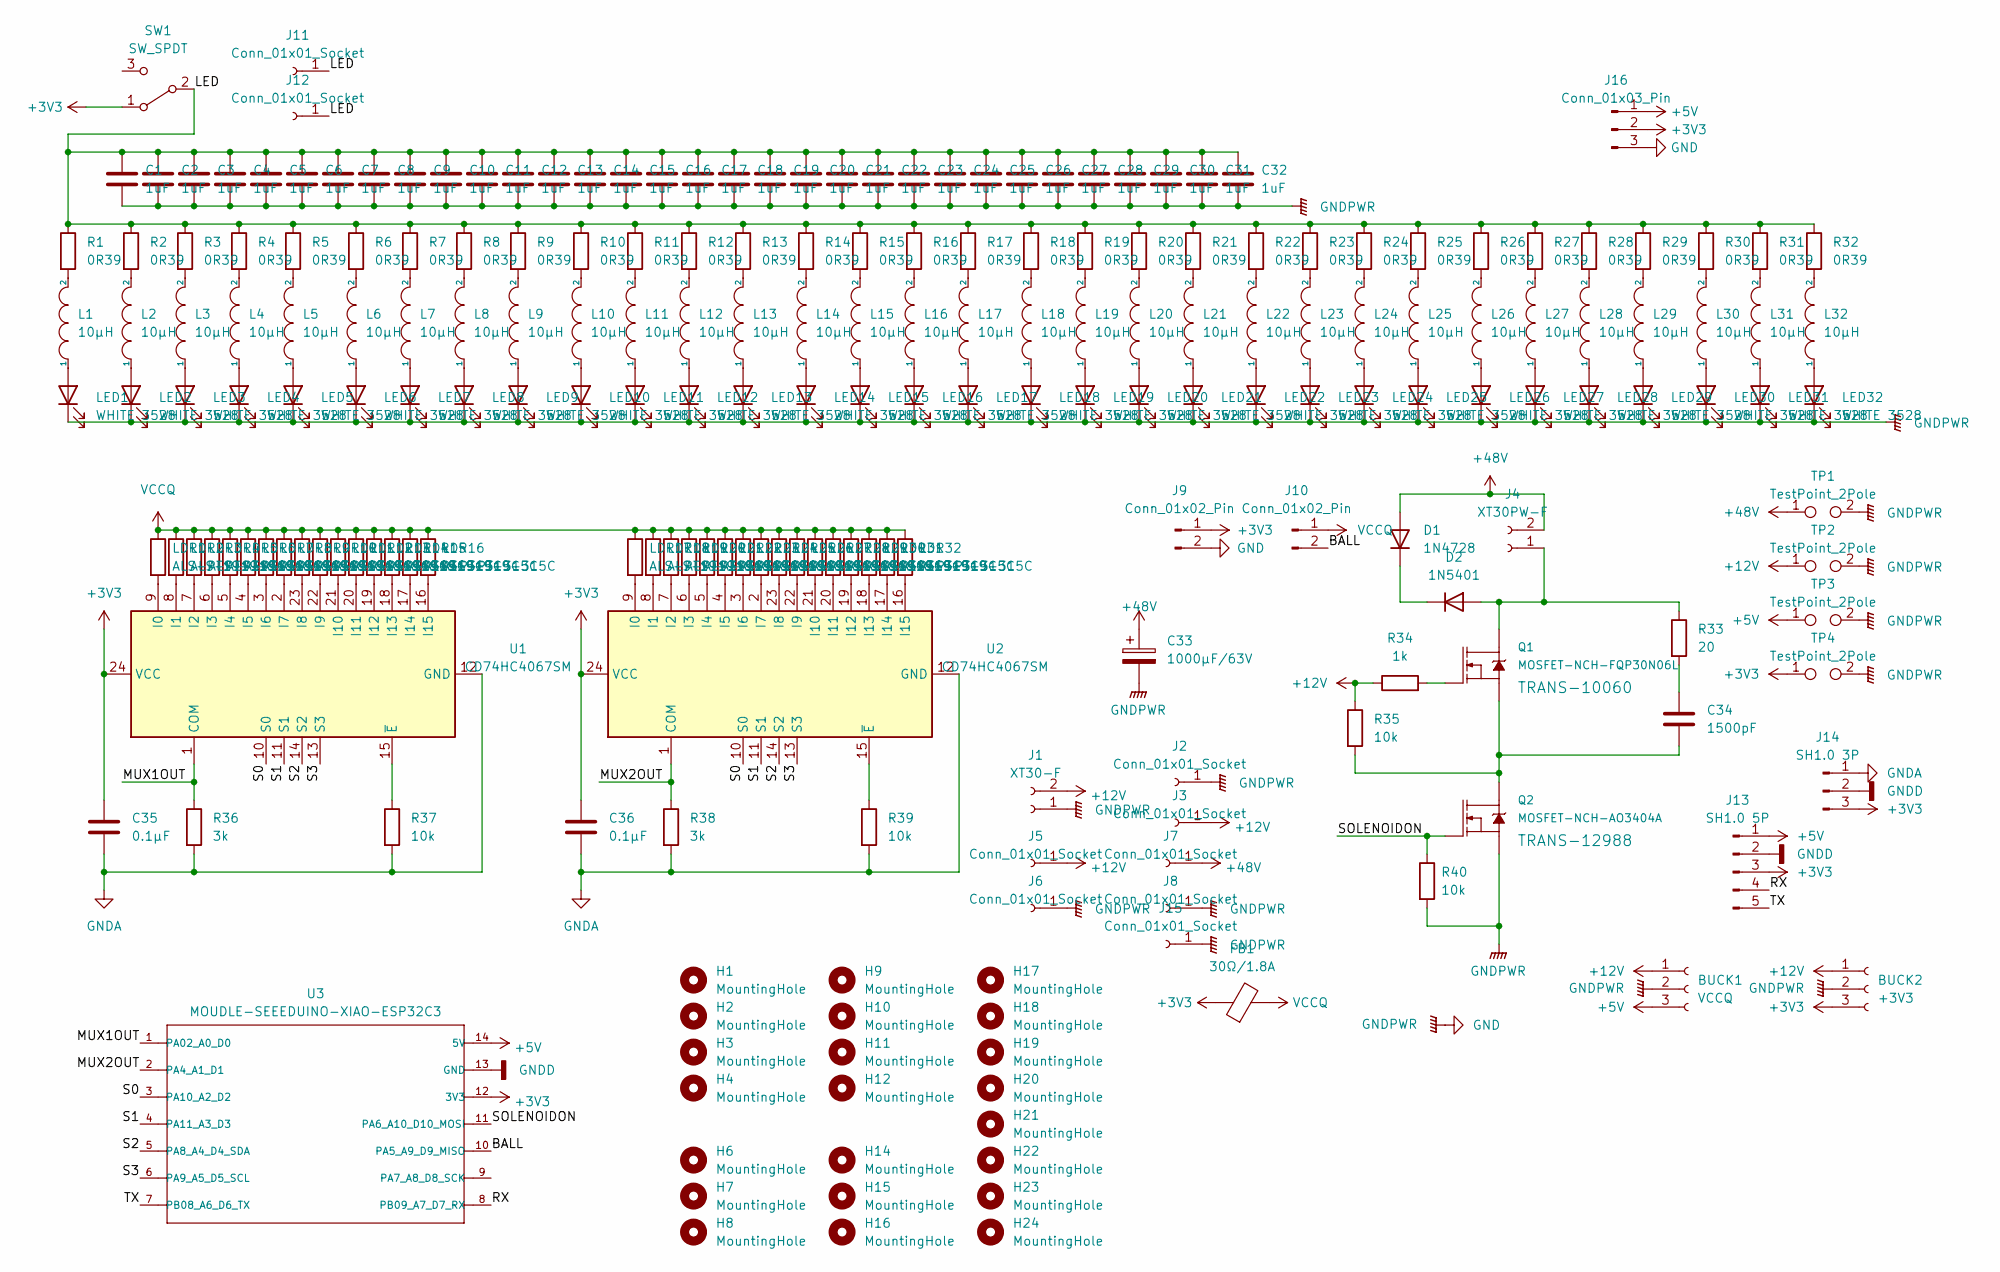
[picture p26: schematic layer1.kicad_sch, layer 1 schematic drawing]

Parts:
BUCK1: VCCQ; PinSocket_1x03_P2.54mm_Horizontal
BUCK2: +3V3; PinSocket_1x03_P2.54mm_Horizontal
C1, C2, C3, C4, C5, C6, C7, C8, C9, C10, C11, C12, C13, C14, C15, C16, C17, C18, C19, C20, C21, C22, C23, C24, C25, C26, C27, C28, C29, C30, C31, C32: 1uF; C_0603_1608Metric
C33: 1000µF/63V; CP_Radial_D16.0mm_P7.50mm
C34: 1500pF; C_0603_1608Metric
C35, C36: 0.1μF; C_0603_1608Metric
D1: 1N4728; D_DO-41_SOD81_P10.16mm_Horizontal
D2: 1N5401; D_DO-27_P15.24mm_Horizontal
FB1: 30Ω/1.8A; C_0603_1608Metric
H1, H2, H3, H4, H6, H7, H8, H9, H10, H11, H12, H14, H15, H16, H17, H18, H19, H20, H21, H22, H23, H24: MountingHole; MountingHole_3.2mm_M3_Pad
J1: XT30-F; AMASS_XT30UPB-F_1x02_P5.0mm_Vertical
J2, J11, J15: Conn_01x01_Socket; SolderWirePad_1x01_SMD_1x2mm
J3, J5, J6, J7, J8: Conn_01x01_Socket; SolderWirePad_1x01_SMD_5x10mm
J4: XT30PW-F; AMASS_XT30UPB-F_1x02_P5.0mm_Vertical
J9, J10: Conn_01x02_Pin; PinHeader_1x02_P2.54mm_Vertical
J12: Conn_01x01_Socket; SolderWire-0.5sqmm_1x01_D0.9mm_OD2.1mm
J13: SH1.0 5P; JST_SH_BM05B-SRSS-TB_1x05-1MP_P1.00mm_Vertical
J14: SH1.0 3P; JST_SH_BM03B-SRSS-TB_1x03-1MP_P1.00mm_Vertical
J16: Conn_01x03_Pin; JST_XH_B3B-XH-A_1x03_P2.50mm_Vertical
L1, L2, L3, L4, L5, L6, L7, L8, L9, L10, L11, L12, L13, L14, L15, L16, L17, L18, L19, L20, L21, L22, L23, L24, L25, L26, L27, L28, L29, L30, L31, L32: 10µH; L_0805_2012Metric
LDR1, LDR2, LDR3, LDR4, LDR5, LDR6, LDR7, LDR8, LDR9, LDR10, LDR11, LDR12, LDR13, LDR14, LDR15, LDR16, LDR17, LDR18, LDR19, LDR20, LDR21, LDR22, LDR23, LDR24, LDR25, LDR26, LDR27, LDR28, LDR29, LDR30, LDR31, LDR32: ALS-PT19-315C; D_0603_1608Metric
LED1, LED2, LED3, LED4, LED5, LED6, LED7, LED8, LED9, LED10, LED11, LED12, LED13, LED14, LED15, LED16, LED17, LED18, LED19, LED20, LED21, LED22, LED23, LED24, LED25, LED26, LED27, LED28, LED29, LED30, LED31, LED32: WHITE 3528; CP_EIA-3528-12_Kemet-T
Q1: MOSFET-NCH-FQP30N06L; TO-220-3_Vertical
Q2: MOSFET-NCH-AO3404A; TSOT-23
R1, R2, R3, R4, R5, R6, R7, R8, R9, R10, R11, R12, R13, R14, R15, R16, R17, R18, R19, R20, R21, R22, R23, R24, R25, R26, R27, R28, R29, R30, R31, R32: 0R39; R_0603_1608Metric
R33: 20; R_0603_1608Metric
R34: 1k; R_0603_1608Metric
R35, R37, R39, R40: 10k; R_0603_1608Metric
R36, R38: 3k; R_0603_1608Metric
SW1: SW_SPDT; SWITCH_SPDT_PTH_11.6X4.0MM
TP1, TP2, TP3, TP4: TestPoint_2Pole; TestPoint_2Pads_Pitch2.54mm_Drill0.8mm
U1, U2: CD74HC4067SM; SOIC-24W_7.5x15.4mm_P1.27mm
U3: MOUDLE-SEEEDUINO-XIAO-ESP32C3; xiao-esp32c3

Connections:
+3V3: BUCK2.3, C35.1, C36.1, FB1.1, J9.1, J13.3, J14.3, J16.2, SW1.1 (A), TP4.1, U1.24 (VCC), U2.24 (VCC), U3.12 (3V3)
+5V: BUCK1.3, J13.1, J16.1, TP3.1, U3.14 (5V)
+12V: BUCK1.1, BUCK2.1, J1.2, J3.1, J5.1, R34.1, R35.1, TP2.1
+48V: C33.1, D1.2 (A), J4.2, J7.1, TP1.1
/BALL: J10.2, U3.10 (PA5_A9_D9_MISO)
/LED: C1.1, C2.1, C3.1, C4.1, C5.1, C6.1, C7.1, C8.1, C9.1, C10.1, C11.1, C12.1, C13.1, C14.1, C15.1, C16.1, C17.1, C18.1, C19.1, C20.1, C21.1, C22.1, C23.1, C24.1, C25.1, C26.1, C27.1, C28.1, C29.1, C30.1, C31.1, C32.1, J11.1, J12.1, R1.1, R2.1, R3.1, R4.1, R5.1, R6.1, R7.1, R8.1, R9.1, R10.1, R11.1, R12.1, R13.1, R14.1, R15.1, R16.1, R17.1, R18.1, R19.1, R20.1, R21.1, R22.1, R23.1, R24.1, R25.1, R26.1, R27.1, R28.1, R29.1, R30.1, R31.1, R32.1, SW1.2 (B)
/MUX1OUT: R36.1, U1.1 (COM), U3.1 (PA02_A0_D0)
/MUX2OUT: R38.1, U2.1 (COM), U3.2 (PA4_A1_D1)
/RX: J13.4, U3.8 (PB09_A7_D7_RX)
/S0: U1.10 (S0), U2.10 (S0), U3.3 (PA10_A2_D2)
/S1: U1.11 (S1), U2.11 (S1), U3.4 (PA11_A3_D3)
/S2: U1.14 (S2), U2.14 (S2), U3.5 (PA8_A4_D4_SDA)
/S3: U1.13 (S3), U2.13 (S3), U3.6 (PA9_A5_D5_SCL)
/SOLENOIDON: Q2.1 (G), R40.1, U3.11 (PA6_A10_D10_MOSI)
/TX: J13.5, U3.7 (PB08_A6_D6_TX)
GND: BUCK1.2, BUCK2.2, C1.2, C2.2, C3.2, C4.2, C5.2, C6.2, C7.2, C8.2, C9.2, C10.2, C11.2, C12.2, C13.2, C14.2, C15.2, C16.2, C17.2, C18.2, C19.2, C20.2, C21.2, C22.2, C23.2, C24.2, C25.2, C26.2, C27.2, C28.2, C29.2, C30.2, C31.2, C32.2, C33.2, J1.1, J2.1, J6.1, J8.1, J9.2, J15.1, J16.3, LED1.1 (K), LED2.1 (K), LED3.1 (K), LED4.1 (K), LED5.1 (K), LED6.1 (K), LED7.1 (K), LED8.1 (K), LED9.1 (K), LED10.1 (K), LED11.1 (K), LED12.1 (K), LED13.1 (K), LED14.1 (K), LED15.1 (K), LED16.1 (K), LED17.1 (K), LED18.1 (K), LED19.1 (K), LED20.1 (K), LED21.1 (K), LED22.1 (K), LED23.1 (K), LED24.1 (K), LED25.1 (K), LED26.1 (K), LED27.1 (K), LED28.1 (K), LED29.1 (K), LED30.1 (K), LED31.1 (K), LED32.1 (K), Q2.2 (S), R40.2, TP1.2, TP2.2, TP3.2, TP4.2
GNDA: C35.2, C36.2, J14.1, R36.2, R37.2, R38.2, R39.2, U1.12 (GND), U2.12 (GND)
GNDD: J13.2, J14.2, U3.13 (GND)
unnamed: C34.1, R33.2
unnamed: D1.1 (K), D2.1 (K)
unnamed: D2.2 (A), J4.1, Q1.2 (D), R33.1
unnamed: L1.2, R1.2
unnamed: L2.2, R2.2
unnamed: L3.2, R3.2
unnamed: L4.2, R4.2
unnamed: L5.2, R5.2
unnamed: L6.2, R6.2
unnamed: L7.2, R7.2
unnamed: L8.2, R8.2
unnamed: L9.2, R9.2
unnamed: L10.2, R10.2
unnamed: L11.2, R11.2
unnamed: L12.2, R12.2
unnamed: L13.2, R13.2
unnamed: L14.2, R14.2
unnamed: L15.2, R15.2
unnamed: L16.2, R16.2
unnamed: L17.2, R17.2
unnamed: L18.2, R18.2
unnamed: L19.2, R19.2
unnamed: L20.2, R20.2
unnamed: L21.2, R21.2
unnamed: L22.2, R22.2
unnamed: L23.2, R23.2
unnamed: L24.2, R24.2
unnamed: L25.2, R25.2
unnamed: L26.2, R26.2
unnamed: L27.2, R27.2
unnamed: L28.2, R28.2
unnamed: L29.2, R29.2
unnamed: L30.2, R30.2
unnamed: L31.2, R31.2
unnamed: L32.2, R32.2
unnamed: L1.1, LED1.2 (A)
unnamed: L2.1, LED2.2 (A)
unnamed: L3.1, LED3.2 (A)
unnamed: L4.1, LED4.2 (A)
unnamed: L5.1, LED5.2 (A)
unnamed: L6.1, LED6.2 (A)
unnamed: L7.1, LED7.2 (A)
unnamed: L8.1, LED8.2 (A)
unnamed: L9.1, LED9.2 (A)
unnamed: L10.1, LED10.2 (A)
unnamed: L11.1, LED11.2 (A)
unnamed: L12.1, LED12.2 (A)
unnamed: L13.1, LED13.2 (A)
unnamed: L14.1, LED14.2 (A)
unnamed: L15.1, LED15.2 (A)
unnamed: L16.1, LED16.2 (A)
unnamed: L17.1, LED17.2 (A)
unnamed: L18.1, LED18.2 (A)
unnamed: L19.1, LED19.2 (A)
unnamed: L20.1, LED20.2 (A)
unnamed: L21.1, LED21.2 (A)
unnamed: L22.1, LED22.2 (A)
unnamed: L23.1, LED23.2 (A)
unnamed: L24.1, LED24.2 (A)
unnamed: L25.1, LED25.2 (A)
unnamed: L26.1, LED26.2 (A)
unnamed: L27.1, LED27.2 (A)
unnamed: L28.1, LED28.2 (A)
unnamed: L29.1, LED29.2 (A)
unnamed: L30.1, LED30.2 (A)
unnamed: L31.1, LED31.2 (A)
unnamed: L32.1, LED32.2 (A)
unnamed: Q1.1 (G), R34.2
unnamed: C34.2, Q1.3 (S), Q2.3 (D), R35.2
unnamed: LDR1.2, U1.9 (I0)
unnamed: LDR2.2, U1.8 (I1)
unnamed: LDR3.2, U1.7 (I2)
unnamed: LDR4.2, U1.6 (I3)
unnamed: LDR5.2, U1.5 (I4)
unnamed: LDR6.2, U1.4 (I5)
unnamed: LDR7.2, U1.3 (I6)
unnamed: LDR8.2, U1.2 (I7)
unnamed: LDR9.2, U1.23 (I8)
unnamed: LDR10.2, U1.22 (I9)
unnamed: LDR11.2, U1.21 (I10)
unnamed: LDR12.2, U1.20 (I11)
unnamed: LDR13.2, U1.19 (I12)
unnamed: LDR14.2, U1.18 (I13)
unnamed: LDR15.2, U1.17 (I14)
unnamed: LDR16.2, U1.16 (I15)
unnamed: R37.1, U1.15 (~E)
unnamed: LDR17.2, U2.9 (I0)
unnamed: LDR18.2, U2.8 (I1)
unnamed: LDR19.2, U2.7 (I2)
unnamed: LDR20.2, U2.6 (I3)
unnamed: LDR21.2, U2.5 (I4)
unnamed: LDR22.2, U2.4 (I5)
unnamed: LDR23.2, U2.3 (I6)
unnamed: LDR24.2, U2.2 (I7)
unnamed: LDR25.2, U2.23 (I8)
unnamed: LDR26.2, U2.22 (I9)
unnamed: LDR27.2, U2.21 (I10)
unnamed: LDR28.2, U2.20 (I11)
unnamed: LDR29.2, U2.19 (I12)
unnamed: LDR30.2, U2.18 (I13)
unnamed: LDR31.2, U2.17 (I14)
unnamed: LDR32.2, U2.16 (I15)
unnamed: R39.1, U2.15 (~E)
VCCQ: FB1.2, J10.1, LDR1.1, LDR2.1, LDR3.1, LDR4.1, LDR5.1, LDR6.1, LDR7.1, LDR8.1, LDR9.1, LDR10.1, LDR11.1, LDR12.1, LDR13.1, LDR14.1, LDR15.1, LDR16.1, LDR17.1, LDR18.1, LDR19.1, LDR20.1, LDR21.1, LDR22.1, LDR23.1, LDR24.1, LDR25.1, LDR26.1, LDR27.1, LDR28.1, LDR29.1, LDR30.1, LDR31.1, LDR32.1

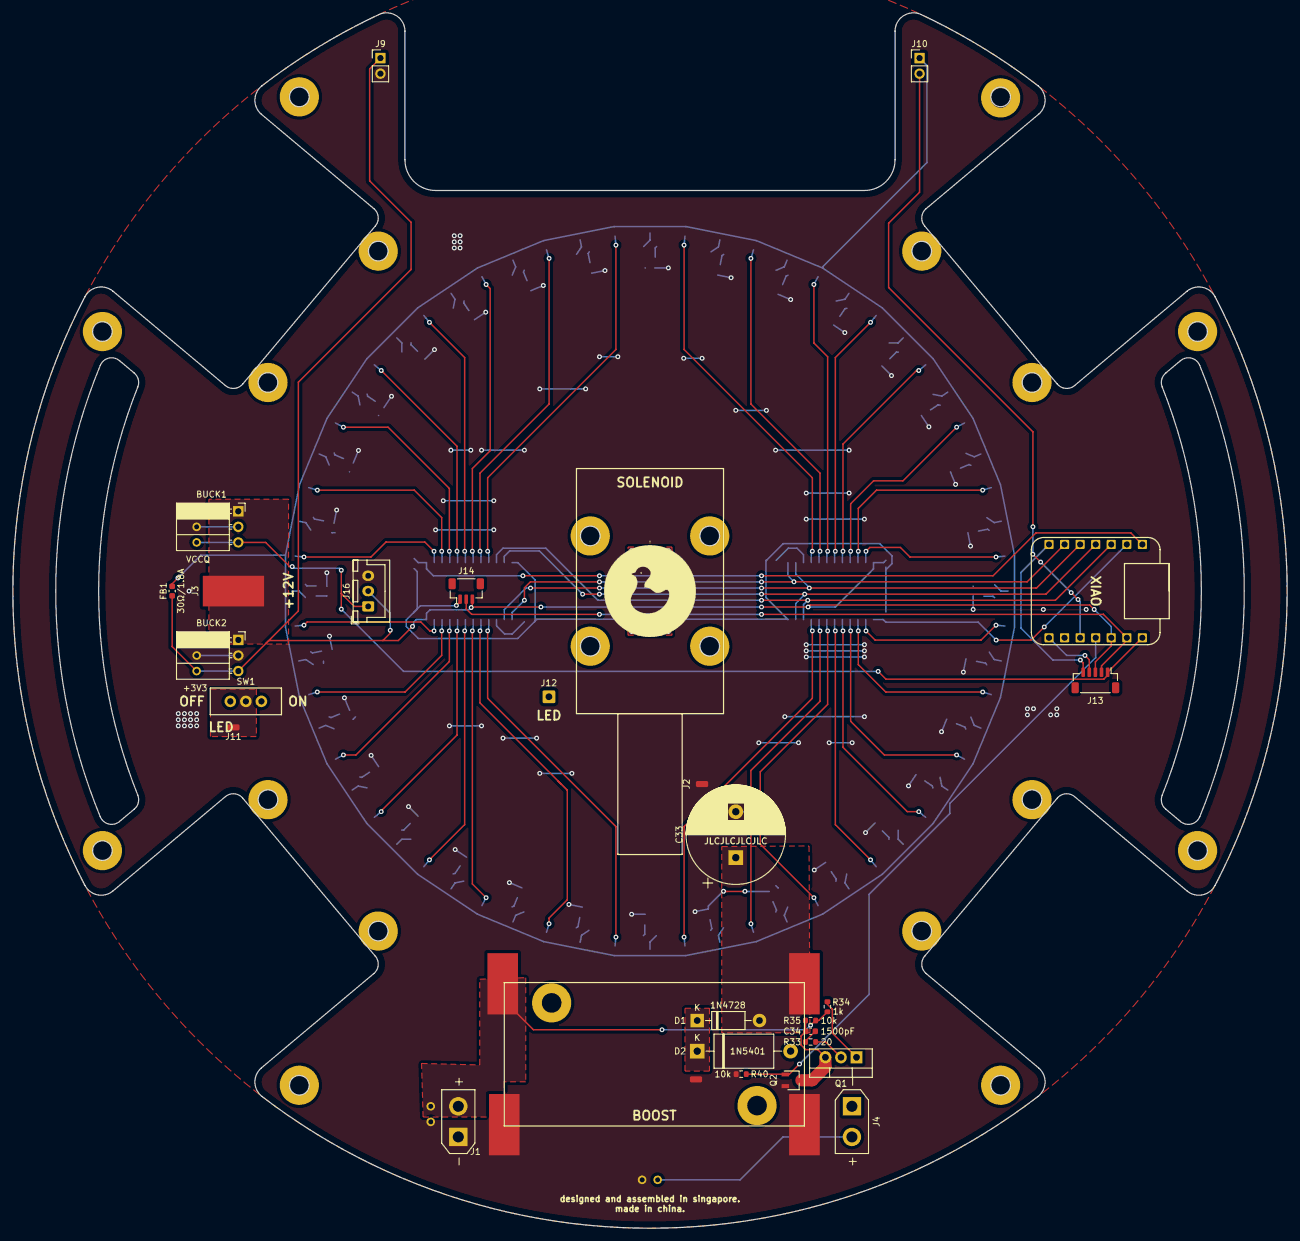
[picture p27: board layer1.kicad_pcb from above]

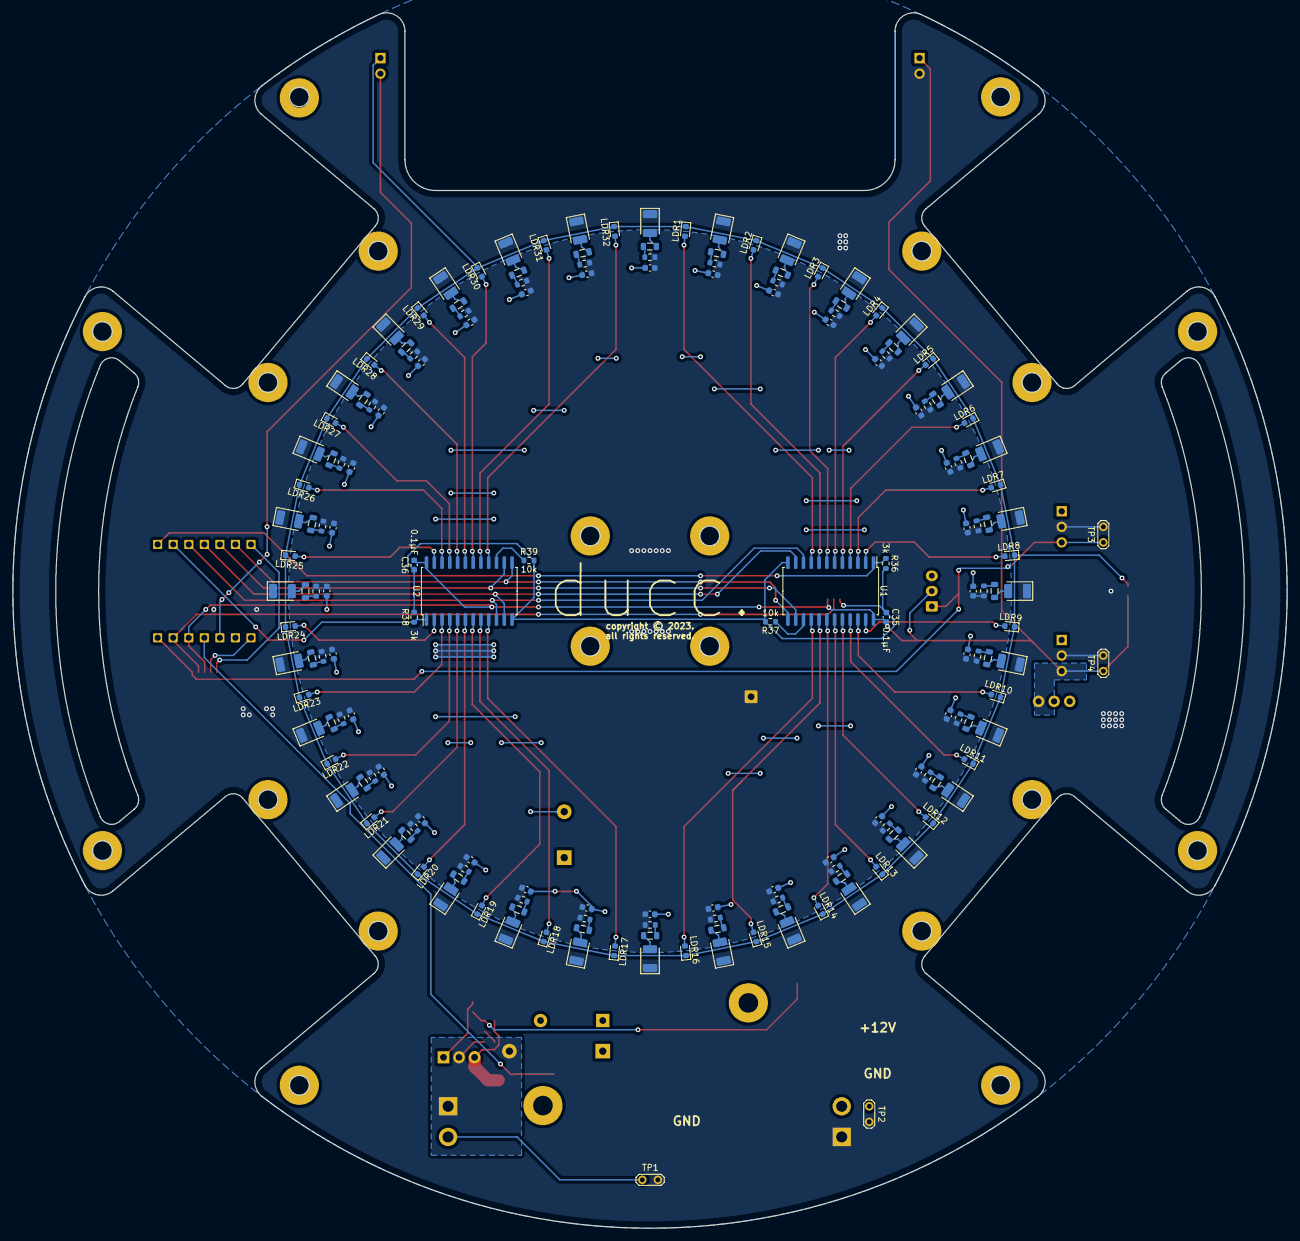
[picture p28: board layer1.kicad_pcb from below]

Board: 2 copper layers, 208.0 x 198.4 mm, 225 parts (172 on the bottom side), 122 nets.

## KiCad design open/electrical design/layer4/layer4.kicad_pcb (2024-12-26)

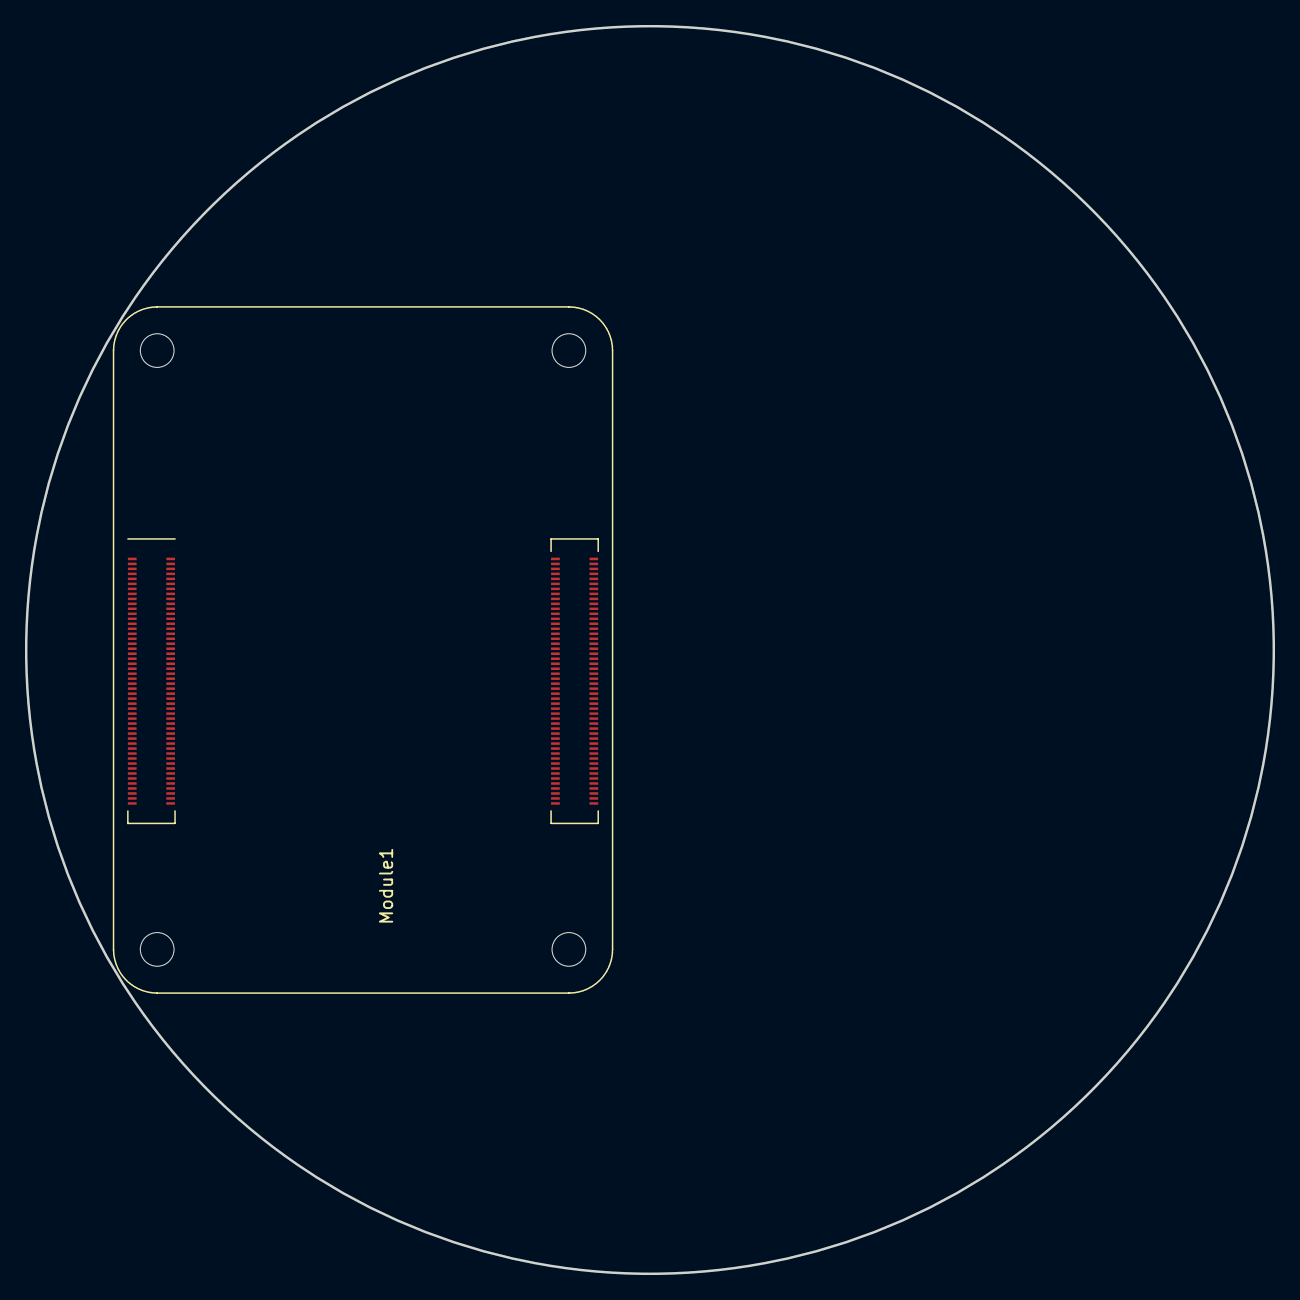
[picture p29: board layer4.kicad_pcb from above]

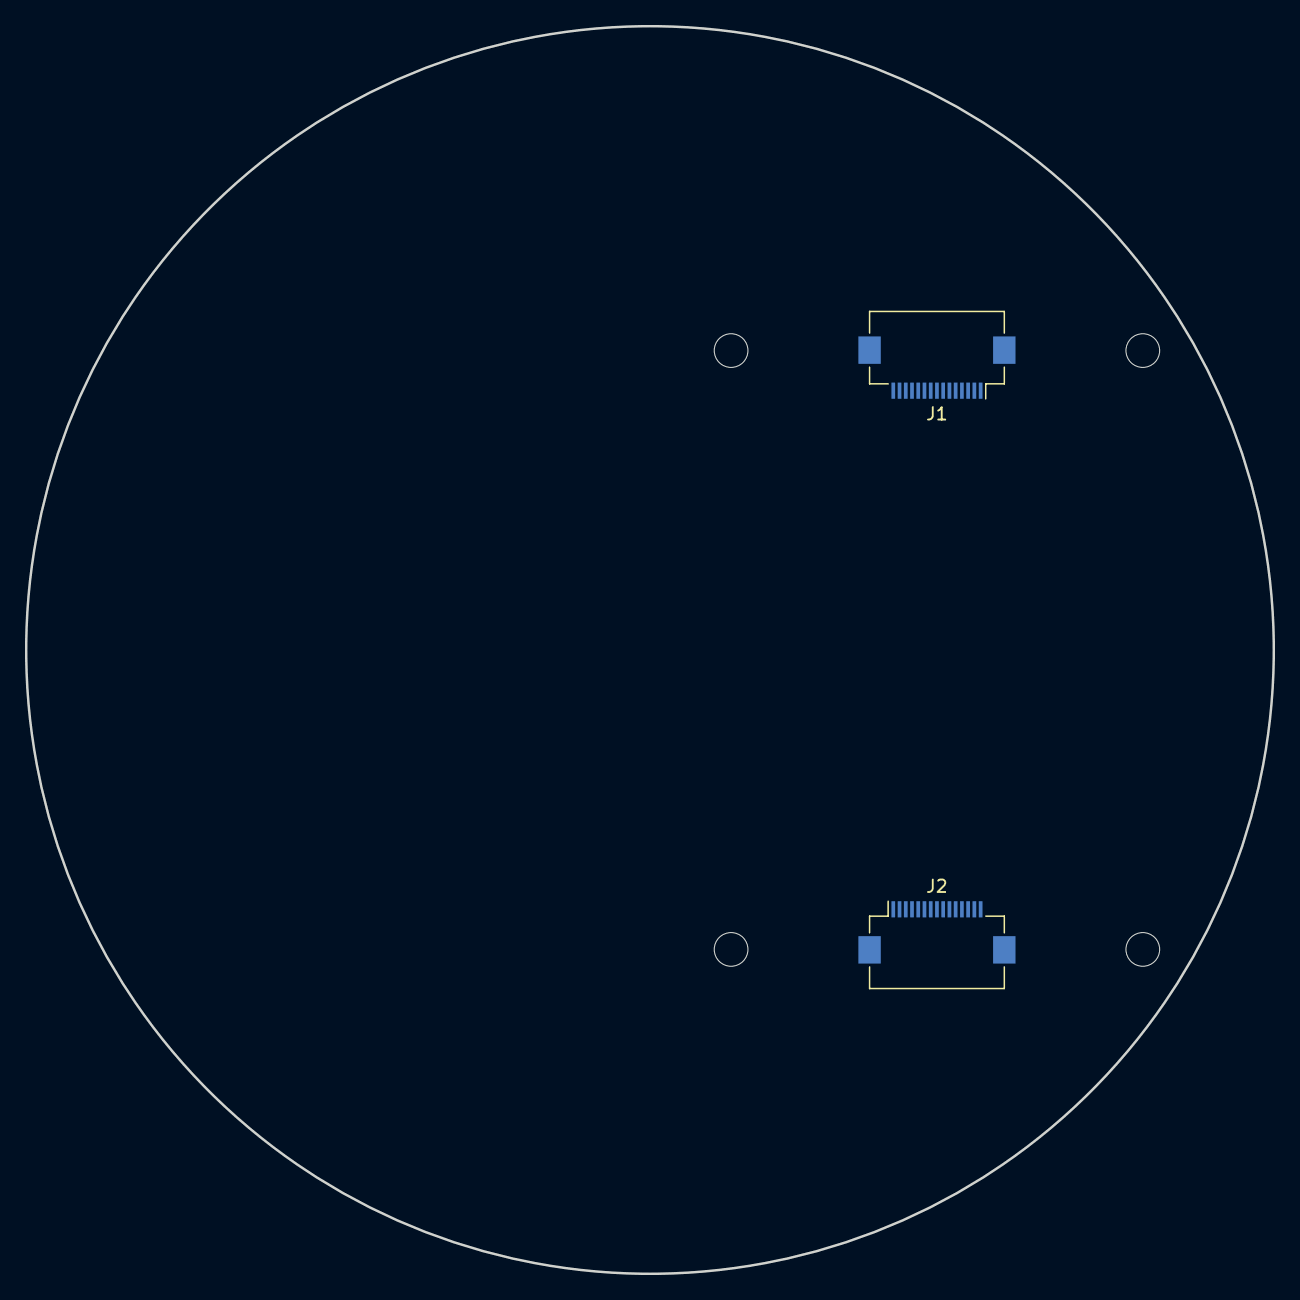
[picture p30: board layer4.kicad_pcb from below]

Board: 2 copper layers, 100.0 x 100.0 mm, 3 parts (2 on the bottom side), 20 nets, no tracks yet.

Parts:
J1, J2: Conn_01x15_Female; Hirose_FH12-15S-0.5SH_1x15-1MP_P0.50mm_Horizontal
Module1: ComputeModule4-CM4; Raspberry-Pi-4-Compute-Module

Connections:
+3V3: J1.15, J2.15, Module1.78 (GPIO_VREF(1.8v/3.3v_Input)), Module1.84 (+3.3v_(Output)), Module1.86 (+3.3v_(Output))
+5V: Module1.77 (+5v_(Input)), Module1.79 (+5v_(Input)), Module1.81 (+5v_(Input)), Module1.83 (+5v_(Input)), Module1.85 (+5v_(Input)), Module1.87 (+5v_(Input))
/rpi1/CAM0_C_N: J1.8, Module1.140 (CAM0_C_N)
/rpi1/CAM0_C_P: J1.9, Module1.142 (CAM0_C_P)
/rpi1/CAM0_D0_N: J1.2, Module1.128 (CAM0_D0_N)
/rpi1/CAM0_D0_P: J1.3, Module1.130 (CAM0_D0_P)
/rpi1/CAM0_D1_N: J1.5, Module1.134 (CAM0_D1_N)
/rpi1/CAM0_D1_P: J1.6, Module1.136 (CAM0_D1_P)
/rpi1/CAM1_C_N: J2.8, Module1.127 (CAM1_C_N)
/rpi1/CAM1_C_P: J2.9, Module1.129 (CAM1_C_P)
/rpi1/CAM1_D0_N: J2.2, Module1.115 (CAM1_D0_N)
/rpi1/CAM1_D0_P: J2.3, Module1.117 (CAM1_D0_P)
/rpi1/CAM1_D1_N: J2.5, Module1.121 (CAM1_D1_N)
/rpi1/CAM1_D1_P: J2.6, Module1.123 (CAM1_D1_P)
/rpi1/CAM_GPIO: J1.11, J2.11, Module1.97 (Camera_GPIO)
/rpi1/ID_SCL: J2.13, Module1.35 (ID_SC)
/rpi1/ID_SDA: J2.14, Module1.36 (ID_SD)
/rpi1/SCL0: J1.13, Module1.80 (SCL0)
/rpi1/SDA0: J1.14, Module1.82 (SDA0)
GND: J1.1, J1.4, J1.7, J1.10, J2.1, J2.4, J2.7, J2.10, Module1.1 (GND), Module1.2 (GND), Module1.7 (GND), Module1.8 (GND), Module1.13 (GND), Module1.14 (GND), Module1.22 (GND), Module1.23 (GND), Module1.32 (GND), Module1.33 (GND), Module1.42 (GND), Module1.43 (GND), Module1.52 (GND), Module1.53 (GND), Module1.59 (GND), Module1.60 (GND), Module1.65 (GND), Module1.66 (GND), Module1.71 (GND), Module1.74 (GND), Module1.98 (GND), Module1.107 (GND), Module1.108 (GND), Module1.113 (GND), Module1.114 (GND), Module1.119 (GND), Module1.120 (GND), Module1.125 (GND), Module1.126 (GND), Module1.131 (GND), Module1.132 (GND), Module1.137 (GND), Module1.138 (GND), Module1.144 (GND), Module1.150 (GND), Module1.155 (GND), Module1.156 (GND), Module1.161 (GND), Module1.162 (GND), Module1.167 (GND), Module1.168 (GND), Module1.173 (GND), Module1.174 (GND), Module1.179 (GND), Module1.180 (GND), Module1.185 (GND), Module1.186 (GND), Module1.191 (GND), Module1.192 (GND), Module1.197 (GND), Module1.198 (GND)

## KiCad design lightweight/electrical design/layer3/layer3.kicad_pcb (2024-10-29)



Board: 2 copper layers, 188.9 x 115.0 mm, 59 parts (4 on the bottom side), 64 nets.

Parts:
C1, C2, C3, C4: 1μF; C_0603_1608Metric
C5, C6: 1pF; C_0603_1608Metric
D1: BLUE; D_0603_1608Metric
DRIBBLERJ1: Conn_01x03_Male; PinHeader_1x03_P2.54mm_Vertical
H1, H2, H3, H4: MountingHole; MountingHole_3.2mm_M3_Pad
IR1, IR2, IR3, IR4, IR5, IR6, IR7, IR8, IR9, IR10, IR11, IR12, IR13, IR14, IR15, IR16, IR17, IR18, IR19, IR20, IR21, IR22, IR23, IR24: TSSP58038; Vishay_MINICAST-3Pin
J1, J2, J3, J4, J11: SH1.0 5P; JST_SH_SM05B-SRSS-TB_1x05-1MP_P1.00mm_Horizontal
J5: Conn_01x03_Pin; JST_XH_B3B-XH-A_1x03_P2.50mm_Vertical
J6: SH1.0 Female; JST_SH_BM06B-SRSS-TB_1x06-1MP_P1.00mm_Vertical
R1, R4: 1k; R_0603_1608Metric
R2, R5, R8: 10k; R_0603_1608Metric
SW1: SW_SPDT; SWITCH_SPDT_PTH_12.7X6.7MM
SW2: SW_DPDT_x2; SWITCH_SPDT_PTH_11.6X4.0MM_LOCK
SW5: SW_Push; SW_Push_SPST_NO_Alps_SKRK
U1: TEENSY 4.0; Teensy 4.0
U2: MOUDLE-SEEEDUINO-XIAO-ESP32C3; xiao-esp32c3
U3: Conn_01x16_Socket; openmv
U4: BNO085; bno085
U5, U6: 74LVC2G04; SOT-23-6
U7: STM32F103C8T6; LQFP-48_7x7mm_P0.5mm
Y1: Crystal; Crystal_SMD_5032-2Pin_5.0x3.2mm

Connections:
+3V3: IR1.3 (Vs), IR2.3 (Vs), IR3.3 (Vs), IR4.3 (Vs), IR5.3 (Vs), IR6.3 (Vs), IR7.3 (Vs), IR8.3 (Vs), IR9.3 (Vs), IR10.3 (Vs), IR11.3 (Vs), IR12.3 (Vs), IR13.3 (Vs), IR14.3 (Vs), IR15.3 (Vs), IR16.3 (Vs), IR17.3 (Vs), IR18.3 (Vs), IR19.3 (Vs), IR20.3 (Vs), IR21.3 (Vs), IR22.3 (Vs), IR23.3 (Vs), IR24.3 (Vs), J5.2, J11.3, SW1.1 (A), SW2.1 (A), U1.3.3V_2, U2.12 (3V3), U4.JP1_1 (VIN), U5.5 (VCC), U6.5 (VCC)
+5V: J5.1, J11.1, U1.VIN, U2.14 (5V), U3.10
/BTRX: U1.21, U2.7 (PB08_A6_D6_TX)
/BTTX: U1.20, U2.8 (PB09_A7_D7_RX)
/CAMRX: U1.8, U3.1
/CAMTX: U1.7, U3.2
/DRIBBLERPWM: DRIBBLERJ1.1, U1.23
/EN: J1.2, J2.2, J3.2, J4.2, R5.2, SW1.2 (B)
/IMUSCL: U1.19, U4.JP1_4 (SCL)
/IMUSDA: U1.18, U4.JP1_5 (SDA)
/L1RX: J11.4, U1.1
/L1TX: J11.5, U1.0
/M1INA: J1.5, U1.9, U5.1
/M1INB: J1.1, U5.6
/M1PWM: J1.3, U1.2
/M2INA: J2.5, U1.10, U5.3
/M2INB: J2.1, U5.4
/M2PWM: J2.3, U1.3
/M3INA: J3.5, U1.11, U6.1
/M3INB: J3.1, U6.6
/M3PWM: J3.3, U1.4
/M4INA: J4.5, U1.12, U6.3
/M4INB: J4.1, U6.4
/M4PWM: J4.3, U1.5
/ir/DEBUGRX: J6.6, U7.22 (PB11)
/ir/DEBUGTX: J6.5, U7.21 (PB10)
/ir/IR1: IR1.1 (OUT), U7.17 (PA7)
/ir/IR2: IR2.1 (OUT), U7.16 (PA6)
/ir/IR3: IR3.1 (OUT), U7.15 (PA5)
/ir/IR4: IR4.1 (OUT), U7.12 (PA2)
/ir/IR5: IR5.1 (OUT), U7.11 (PA1)
/ir/IR6: IR6.1 (OUT), U7.10 (PA0)
/ir/IR7: IR7.1 (OUT), U7.46 (PB9)
/ir/IR8: IR8.1 (OUT), U7.45 (PB8)
/ir/IR9: IR9.1 (OUT), U7.43 (PB7)
/ir/IR10: IR10.1 (OUT), U7.42 (PB6)
/ir/IR11: IR11.1 (OUT), U7.41 (PB5)
/ir/IR12: IR12.1 (OUT), U7.40 (PB4)
/ir/IR13: IR13.1 (OUT), U7.39 (PB3)
/ir/IR14: IR14.1 (OUT), U7.38 (PA15)
/ir/IR15: IR15.1 (OUT), U7.33 (PA12)
/ir/IR16: IR16.1 (OUT), U7.32 (PA11)
/ir/IR17: IR17.1 (OUT), U7.29 (PA8)
/ir/IR18: IR18.1 (OUT), U7.28 (PB15)
/ir/IR19: IR19.1 (OUT), U7.27 (PB14)
/ir/IR20: IR20.1 (OUT), U7.26 (PB13)
/ir/IR21: IR21.1 (OUT), U7.25 (PB12)
/ir/IR22: IR22.1 (OUT), U7.20 (PB2)
/ir/IR23: IR23.1 (OUT), U7.19 (PB1)
/ir/IR24: IR24.1 (OUT), U7.18 (PB0)
/ir/MCU3V3: C1.2, C2.2, C3.2, C4.2, R8.2, SW2.2 (B), U7.9 (VDDA), U7.24 (VDD), U7.36 (VDD), U7.48 (VDD)
/ir/OSCIN: C5.2, U7.5 (PD0), Y1.2
/ir/OSCOUT: C6.2, U7.6 (PD1), Y1.1
/ir/PROG3V3: J6.4, SW2.3 (C)
/ir/RESET: R8.1, SW5.2, U7.7 (NRST)
/ir/SWDCLOCK: J6.2, U7.37 (PA14)
/ir/SWDIO: J6.3, U7.34 (PA13)
GND: C1.1, C2.1, C3.1, C4.1, C5.1, C6.1, D1.1 (K), DRIBBLERJ1.3, IR1.2 (GND), IR2.2 (GND), IR3.2 (GND), IR4.2 (GND), IR5.2 (GND), IR6.2 (GND), IR7.2 (GND), IR8.2 (GND), IR9.2 (GND), IR10.2 (GND), IR11.2 (GND), IR12.2 (GND), IR13.2 (GND), IR14.2 (GND), IR15.2 (GND), IR16.2 (GND), IR17.2 (GND), IR18.2 (GND), IR19.2 (GND), IR20.2 (GND), IR21.2 (GND), IR22.2 (GND), IR23.2 (GND), IR24.2 (GND), J5.3, J6.1, J11.2, R2.2, R4.1, R5.1, U1.G1, U1.G3, U2.13 (GND), U3.9, U4.JP1_3 (GND), U5.2 (GND), U6.2 (GND), U7.8 (VSSA), U7.23 (VSS), U7.35 (VSS), U7.47 (VSS)
IRRX: U1.14, U7.31 (PA10)
IRTX: U1.15, U7.30 (PA9)
unnamed: D1.2 (A), R1.2
unnamed: R4.2, SW5.1
unnamed: R2.1, U7.44 (BOOT0)
unnamed: R1.1, U7.13 (PA3)

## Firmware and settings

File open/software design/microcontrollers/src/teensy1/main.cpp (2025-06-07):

#include "main.h"
#include "HardwareSerial.h"
#include <TeensyThreads.h>

PacketSerial Layer1Serial;
PacketSerial ImuSerial;
PacketSerial TeensySerial;

Layer1RxDataUnion layer_1_rx_data;
ImuRxDataUnion imu_rx_data;
Teensy1TxDataUnion teensy_1_tx_data;

Robot robot;
Ball ball;

Goal yellow_goal;
Goal blue_goal;

Goal yellow_open;
Goal blue_open;

unsigned long last_time = 0;
int real = 0;
int points = 0;

// striker variables
unsigned long no_catchment_start_time = 0;
bool was_in_catchment = false;
const unsigned long catchment_timeout = 500; // ms

// goalie variables
unsigned long time_ball_stopped;
double ball_last_dist;
bool ball_approaching;

void striker()
{
  if (robot.kicker.kicked)
  {
    was_in_catchment = false; // reset the catchment state
    robot.task = 0;           // running orbitToBall
    return;
  }

  if (ball.in_catchment == 1)
  {
    no_catchment_start_time = millis(); // reset the timer
    was_in_catchment = true;
    robot.task = 1; // running orbitScore
  }
  else if (was_in_catchment) // if ball was previously in catchment, start timing
  {
    if (millis() - no_catchment_start_time > catchment_timeout) // check elapsed time
    {
      robot.task = 0; // running orbitToBall
      was_in_catchment = false;
    }
    else
    {
      robot.task = 1; // continue running orbitScore
    }
  }
  else
  {
    robot.task = 0; // running orbitToBall
  }
}

void goalie()
{
  robot.task = 2; // running defendGoal
}

// volatile int count = 0;

// void resetThread()
// {
//   while (true)
//   {
//     robot.kicker.reset();
//     threads.delay(1);
//   }
// }

// void serialThread()
// {
//   while (1)
//   {

//     count += 1;
//     threads.delay(1);
//   }
// }

// void loopThread()
// {
//   while (true)
//   {
//     robot.sendSerial();
//     robot.updateSerial();
//     // double flick_angle = 0;
//     double kp = 0.0014; // orginally 0.0014
//     double ki = 0.0;    // orginally 0.0
//     double kd = 0.005;  // orginally 0.005

// #ifndef BOT_A
//     // pure goalie code
//     if (!robot.alliance_robot_detected)
//     {
//       if (robot.dip_1_on)
//       {
//         striker();
//       }
//       else
//       {
//         goalie();
//       }
//     }
//     else
//     {
//       if (robot.dip_2_on)
//       {
//         striker();
//       }
//       else
//       {
//         robot.task = 2;
//       }
//     }

// #else
//     // pure striker code
//     // striker();
//     // if (!robot.alliance_robot_detected && ball.current_pose.y < 700)
//     // {
//     //   goalie();
//     // }
//     // else
//     // {
//     //   striker();
//     // }
// #endif

//     // Serial.print("task: ");x
//     // Serial.println(robot.task);

//     switch (robot.task)
//     {
//     case 0:
//       // Serial.println("running task 0");
//       // digitalWrite(13, HIGH);
//       robot.orbitToBall(0);
//       // robot.rotateToBall();
//       break;

//     case 1:
//       // digitalWrite(13, LOW);
//       robot.orbitScore();
//       break;

//     case 2:
//       // digitalWrite(13, HIGH);
//       robot.defendGoal();
//       break;

//     case 3:
//       kp = 0.0013;
//       // robot.moveToTargetPose();
//       break;
//     }
//     // goalie();
//     // Serial.print("blue x: " + String(blue_goal.current_pose.x));

//     striker();

//     // Serial.println("ball: " + String(ball.in_catchment));
//     // digitalWrite(13, HIGH);
//     // robot.kicker.kick();
//     // robot.kicker.reset();
//     // robot.orbitToBall(0);

//     // if (abs(ball.current_pose.x) > 6){
//     //   digitalWrite(13, HIGH);
//     // } else {
//     //   digitalWrite(13, LOW);
//     // }
//     // moveToCenter();÷

//     // robot.target_pose.x = blue_goal.current_pose.x;
//     // robot.target_pose.y = blue_goal.current_pose.y + yellow_goal.current_pose.y;
//     // Serial.println("x: " + String(robot.target_pose.x) + " y: " + String(robot.target_pose.y));
//     // robot.goalieTrack();
//     // Serial.println("angle: " + String(robot.move_data.target_angle) + "bearing: " + String(robot.move_data.target_bearing));

//     robot.base.move(robot.move_data.speed, robot.move_data.target_angle, robot.move_data.target_bearing, kp, ki, kd);
//     threads.delay(1);
//   }
// }

// int enter_sleep(int ms) {
//   delay(ms);//set sleep time in milliseconds
//   //additional, one can use the RTC or a low power timer
//   //to calculate actual time spent asleep and return the
//   //value to the scheduler to calculate better times.
//   return ms;
// }

void setup()
{
  robot.base.setUp();
  robot.setUpSerial();

  robot.previous_pose.x = 0;
  robot.previous_pose.y = 0;
  robot.previous_pose.bearing = 0;

  last_time = millis();
  // robot.dribbler.update();
  // robot.dribbler.dribbling = true;

  // robot.kicker.setup();

  pinMode(13, OUTPUT);
  pinMode(23, OUTPUT);

  delay(1000);

  // digitalWriteFast(23, HIGH);         // Start the pulse
  // delayMicroseconds(2500);     // Wait for 1ms (pulse width for 0 degrees)
  // digitalWriteFast(23, LOW);
  // delay(1500);

  // digitalWriteFast(23, HIGH);
  // delayMicroseconds(500);     // Wait for 1ms (pulse width for 0 degrees)
  // digitalWriteFast(23, LOW);
  // delay(1500);

  // digitalWriteFast(23, HIGH);
  // delayMicroseconds(2300);     // Wait for 1ms (pulse width for 0 degrees)
  // digitalWriteFast(23, LOW);
  // delay(2000);

  // threads.addThread(resetThread, 0, 10000);

  // threads.addThread(loopThread);
  // reset.detach();
  // main.detach();
  // serial.detach();
}

long unsigned timer = 0;
int count = 0;

void loop()
{
  bool kick = false;
  // while (true)
  // {
  //   Serial.println(EEPROM.read(0));
  //   // EEPROM.write(0, 1);
  // }
  // Serial.print("0. : " + String(micros() - timer));
  // timer = micros();
  robot.sendSerial();
  // Serial.println("1.: " + String(micros() - timer));
  // timer = micros();
  robot.updateSerial();
  // Serial.println("2.: " + String(micros() - timer));
  // timer = micros();
  robot.storeRobotPose();
  // Serial.println("3.: " + String(micros() - timer));
  // timer = micros();

  double kp = 0.0014; // orginally 0.0014
  double ki = 0.0;    // orginally 0.0
  double kd = 0.005;  // orginally 0.005
  double ema_constant = 0.005;

  switch (robot.task)
  {
  case 0:
    // Serial.println("running task 0");
    // digitalWrite(13, HIGH);
    if (yellow_goal.detected)
    {
      robot.orbitToBall(blue_open.current_pose.bearing);
    }
    else
    {
      robot.orbitToBall(0);
    }
    // robot.orbitToBall(0);
    ema_constant = 0.005;
    kp = 0.0016;
    // kp = map(robot.move_data.speed, 0, 0.4, 0, 0.0013);
    // kd = map(pow(robot.move_data.speed, 2), 0, 0.16, 0, 0.005);
    // robot.rotateToBall();
    break;

  case 1:
    // digitalWrite(13, LOW);
    kick = robot.orbitScore();
    if (kick)
    {
      // robot.move_data.target_bearing = 0;
      ema_constant = 1;
    }
    else
    {
      if (robot.move_data.speed == 0.05)
      {
        kp = 0.004;
      }
      else if (robot.move_data.speed < 0.12)
      {
        kp = 0.003;
      }
      ema_constant = 0.008;
    }

    break;

  case 2:
    // digitalWrite(13, HIGH);
    robot.defendGoal();
    break;

  case 3:
    kp = 0.0013;
    // robot.moveToTargetPose();
    break;
  }
  // Serial.println("4.: " + String(micros() - timer));
  // timer = micros();
  // goalie();
  striker();

  // Serial.println("5.: " + String(micros() - timer));

  // if (robot.kicker.just_kicked) {
  //   if (millis() - robot.kicker.time_kicked > 1000) {
  //     robot.kicker.just_kicked = false;
  //   }

  //   robot.move_data.speed = 0;
  //   robot.base.move(0, 0, 0, kp, ki, kd);
  //   robot.task = 0; // running orbitToBall
  // } else {
  // ema_constant = 0.01;
  // robot.move_data.speed = 0.05;
  // robot.move_data.target_angle = 0;
  // robot.move_data.target_bearing = 0;

  //  kp = 0.004; // orginally 0.0014
  //  ki = 0.0;    // orginally 0.0
  //  kd = 0.005;  // orginally 0.005
  robot.base.move(robot.move_data.speed, robot.move_data.target_angle, robot.move_data.target_bearing, kp, ki, kd, ema_constant);
  // }

  // if (millis() - timer > 1000) {
  //   timer = millis();
  //   count ++;
  //   if (count > 3) {
  //     count = 0;
  //   }
  // }
  // robot.moveToPoint(0, 0, 0);
  // }

  // Serial.println("x: " + String(robot.current_pose.x) + ", y: " + String(robot.current_pose.y) + " bearing: " + String(robot.current_pose.bearing));
  // Serial.println("blue x: " + String(blue_goal.current_pose.x) + ", goal y: " + String(blue_goal.current_pose.y));
  // Serial.println("yellow x: " + String(yellow_goal.current_pose.x) + ", yellow y: " + String(yellow_goal.current_pose.y));

  // robot.orbitToBall(0);
  // robot.move_data.speed = 0.2;
  // robot.move_data.target_angle = 90*count;
  // robot.move_data.target_bearing = 0;

  // Serial.println("target: " + String(robot.move_data.target_bearing) + "actual: " + String(robot.current_pose.bearing));
  // delayMicroseconds(1);
  // Serial.println("6.: " + String(micros() - timer));
  // timer = micros();
  if (kick)
  {
    // robot.kicker.reset();
    kick = false;
    robot.task = 0;
    robot.base.move(0, 0, robot.move_data.target_bearing, kp, ki, kd, 1);
  }
}

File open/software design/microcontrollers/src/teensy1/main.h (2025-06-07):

#pragma once

#ifndef MAIN_H
#define MAIN_H

// #define DEBUG
// #define SERIAL_DEBUG
#define BOT_A

#include <common.h>
#include <EEPROM.h>
#include <TeensyThreads.h>

#define DRIBBLER_LOWER_LIMIT 32
#define DRIBBLER_UPPER_LIMIT 48

#ifdef BOT_A

#define FL_PWM 3
#define FR_PWM 2
#define BL_PWM 4
#define BR_PWM 5
#define LIDAR_PWM 6
#define DRIBBLER_PWM 23

#define FL_INA 10
#define FR_INA 9
#define BL_INA 11
#define BR_INA 12

#else

#define FL_PWM 2
#define FR_PWM 3
#define BL_PWM 4
#define BR_PWM 5
#define LIDAR_PWM 6
#define DRIBBLER_PWM 23

#define FL_INA 9
#define FR_INA 10
#define BL_INA 11
#define BR_INA 12

#endif

#define FL_CS 17
#define FR_CS 16
#define BL_CS 18
#define BR_CS 19

class Base
{
public:
    void setUp();
    void move(double vel, double angle, double bearing, double kp = 0.0013, double ki = 0.0, double kd = 0.005, double ema_constant = 0.02);
    void motorOut(int motor, double speed);
    double getAggregateSpeed(int motor);

    const double wheel_angle = 50 * M_PI / 180.0;
    const int max_pwm = 8192;
    const int min_speed = 800;
    // const double ema_constant = 0.0002;

    const double fl_voltage = 2.500;
    const double fr_voltage = 2.300;
    const double bl_voltage = 2.282;
    const double br_voltage = 2.480;
    const double fastest_motor = fl_voltage;

    // const double fl_scale = fastest_motor / fl_voltage;
    // const double fr_scale = fastest_motor / fr_voltage;
    // const double bl_scale = fastest_motor / bl_voltage;
    // const double br_scale = fastest_motor / br_voltage;

    const int fl_scale = 1;
    const int fr_scale = 1;
    const int bl_scale = 1;
    const int br_scale = 1;

    double prev_fl_out = 0;
    double prev_fr_out = 0;
    double prev_bl_out = 0;
    double prev_br_out = 0;
};

struct MoveData
{
    double speed;
    double target_angle;
    double target_bearing;
    double ema_constant;
};

struct LineData
{
    bool on_line;
    bool already_on_line;

    double initial_line_angle;
    double line_angle;
    int chord_length;
    double line_centre;

    float line_start_ldr;
    float line_end_ldr;

    float ldr_angles[15][32] = {
        {
            318.43,
            324.19,
            329.99,
            335.86,
            341.87,
            348.16,
            355.30,
            8.36,
            171.64,
            184.70,
            191.84,
            198.13,
            204.14,
            210.01,
            215.81,
            221.57,
            227.31,
            233.03,
            238.73,
            244.42,
            250.11,
            255.80,
            261.48,
            267.16,
            272.84,
            278.52,
            284.20,
            289.89,
            295.58,
            301.27,
            306.97,
            312.69,
        },
        {
            320.31,
            326.49,
            332.84,
            339.47,
            346.62,
            354.91,
            6.50,
            36.04,
            143.96,
            173.50,
            185.09,
            193.38,
            200.53,
            207.16,
            213.51,
            219.69,
            225.76,
            231.76,
            237.70,
            243.62,
            249.50,
            255.37,
            261.23,
            267.08,
            272.92,
            278.77,
            284.63,
            290.50,
            296.38,
            302.30,
            308.24,
            314.24,
        },
        {
            323.61,
            330.51,
            337.79,
            345.70,
            354.74,
            6.11,
            23.38,
            59.09,
            120.91,
            156.62,
            173.89,
            185.26,
            194.30,
            202.21,
            209.49,
            216.39,
            223.04,
            229.53,
            235.91,
            242.20,
            248.43,
            254.62,
            260.78,
            266.93,
            273.07,
            279.22,
            285.38,
            291.57,
            297.80,
            304.09,
            310.47,
            316.96,
        },
        {
            328.53,
            336.46,
            345.04,
            354.63,
            5.93,
            20.35,
            40.72,
            71.21,
            108.79,
            139.28,
            159.65,
            174.07,
            185.37,
            194.96,
            203.54,
            211.47,
            218.97,
            226.19,
            233.19,
            240.05,
            246.80,
            253.48,
            260.10,
            266.70,
            273.30,
            279.90,
            286.52,
            293.20,
            299.95,
            306.81,
            313.81,
            321.03,
        },
        {
            335.31,
            344.51,
            354.55,
            5.82,
            18.92,
            34.70,
            54.12,
            77.43,
            102.57,
            125.88,
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

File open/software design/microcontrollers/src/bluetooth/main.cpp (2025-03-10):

/**
 * A BLE client example that is rich in capabilities.
 * There is a lot new capabilities implemented.
 * author unknown
 * updated by chegewara and MoThunderz
 */

#include "main.h"

// TRANSFER to teensy
BtTxDataUnion tx_data;

// receive from other robot
BtRxDataUnion external_rx_data;

// transfer to other robot; RECEIVE from teensy
BtRxDataUnion rx_data;

PacketSerial TeensySerial;

#define BOT_A

void onTeensyReceived(const byte *buf, size_t size)
{
    // Read the payload
    BtRxDataUnion data_received;
    // Don't continue if the payload is invalid
    if (size != sizeof(data_received))
        return;
    std::copy(buf, buf + size, std::begin(data_received.bytes));

    rx_data.data.ball_detected = data_received.data.ball_detected;
    rx_data.data.ball_pose = data_received.data.ball_pose;
    rx_data.data.robot_pose = data_received.data.robot_pose;

    // Serial.print("Robot Pose: ");
    // Serial.print(rx_data.data.robot_pose.x);
    // Serial.print(", ");
    // Serial.print(rx_data.data.robot_pose.y);
    // Serial.print(", ");
    // Serial.println(rx_data.data.robot_pose.bearing);
}

#ifdef BOT_A
#include "BLEDevice.h"
// #include "BLEScan.h"

// Define UUIDs:
static BLEUUID serviceUUID("d9c3070a-96b8-4053-8115-e3af0af0207f");
static BLEUUID charUUID_1("1ad3eb69-dbe5-496d-a66e-5c3c9cf44d56");
static BLEUUID charUUID_2("66857cb2-b396-44da-99bc-029e6b4731d4");

// Some variables to keep track on device connected
static boolean doConnect = false;
static boolean connected = false;
static boolean doScan = false;
int last_connect_time = 99999999;

// Define pointer for the BLE connection
static BLEAdvertisedDevice *myDevice;
BLERemoteCharacteristic *pRemoteChar_1;
BLERemoteCharacteristic *pRemoteChar_2;

BtTxData txData;
BtRxData rxData;

// Callback function for Notify function
static void notifyCallback(BLERemoteCharacteristic *pBLERemoteCharacteristic,
                           uint8_t *pData,
                           size_t length,
                           bool isNotify)
{
    if (pBLERemoteCharacteristic->getUUID().toString() == charUUID_1.toString())
    {

        // convert received bytes to integer
        uint32_t counter = pData[0];
        for (int i = 1; i < length; i++)
        {
            counter = counter | (pData[i] << i * 8);
        }

        // print to Serial
        Serial.print("Characteristic 1 (Notify) from server: ");
        Serial.println(counter);
    }
}

// Callback function that is called whenever a client is connected or disconnected
class MyClientCallback : public BLEClientCallbacks
{
    void onConnect(BLEClient *pclient)
    {
    }

    void onDisconnect(BLEClient *pclient)
    {
        connected = false;
    }
};

// Function to chech Characteristic
bool connectCharacteristic(BLERemoteService *pRemoteService, BLERemoteCharacteristic *l_BLERemoteChar)
{
    // Obtain a reference to the characteristic in the service of the remote BLE server.
    if (l_BLERemoteChar == nullptr)
    {
        Serial.print("Failed to find one of the characteristics");
        Serial.print(l_BLERemoteChar->getUUID().toString().c_str());
        return false;
    }
    Serial.println(" - Found characteristic: " + String(l_BLERemoteChar->getUUID().toString().c_str()));

    if (l_BLERemoteChar->canNotify())
        l_BLERemoteChar->registerForNotify(notifyCallback);

    return true;
}

// Function that is run whenever the server is connected
bool connectToServer()
{
    Serial.print("Forming a connection to ");
    Serial.println(myDevice->getAddress().toString().c_str());

    BLEClient *pClient = BLEDevice::createClient();
    Serial.println(" - Created client");

    pClient->setClientCallbacks(new MyClientCallback());

    // Connect to the remove BLE Server.
    pClient->connect(myDevice); // if you pass BLEAdvertisedDevice instead of address, it will be recognized type of peer device address (public or private)
    Serial.println(" - Connected to server");

    // Obtain a reference to the service we are after in the remote BLE server.
    BLERemoteService *pRemoteService = pClient->getService(serviceUUID);
    if (pRemoteService == nullptr)
    {
        Serial.print("Failed to find our service UUID: ");
        Serial.println(serviceUUID.toString().c_str());
        pClient->disconnect();
        return false;
    }
    Serial.println(" - Found our service");

    connected = true;
    pRemoteChar_1 = pRemoteService->getCharacteristic(charUUID_1);
    pRemoteChar_2 = pRemoteService->getCharacteristic(charUUID_2);
    if (connectCharacteristic(pRemoteService, pRemoteChar_1) == false)
        connected = false;
    else if (connectCharacteristic(pRemoteService, pRemoteChar_2) == false)
        connected = false;

    if (connected == false)
    {
        pClient->disconnect();
        Serial.println("At least one characteristic UUID not found");
        return false;
    }
    return true;
}

// Scan for BLE servers and find the first one that advertises the service we are looking for.
class MyAdvertisedDeviceCallbacks : public BLEAdvertisedDeviceCallbacks
{
    // Called for each advertising BLE server.
    void onResult(BLEAdvertisedDevice advertisedDevice)
    {
        Serial.print("BLE Advertised Device found: ");
        Serial.println(advertisedDevice.toString().c_str());
        tx_data.data.robot_detected = false;

        // We have found a device, let us now see if it contains the service we are looking for.
        if (advertisedDevice.haveServiceUUID() && advertisedDevice.isAdvertisingService(serviceUUID))
        {

            BLEDevice::getScan()->stop();
            myDevice = new BLEAdvertisedDevice(advertisedDevice);
            doConnect = true;
            doScan = true;

        } // Found our server
    }     // onResult
};        // MyAdvertisedDeviceCallbacks

void setup()
{
#ifdef SERIAL_DEBUG
    Serial.begin(serial_monitor_baud);
    Serial.println("Starting Arduino BLE Client application...");
    BLEDevice::init("");
#endif

    Serial0.begin(bt_serial_baud);
    // Serial0.setTxBufferSize(120);
    // Serial0.setRxBufferSize(120);
    while (!Serial0)
    {
    }
    TeensySerial.setStream(&Serial0);
    TeensySerial.setPacketHandler(&onTeensyReceived);

    // Retrieve a Scanner and set the callback we want to use to be informed when we
    // have detected a new device.  Specify that we want active scanning and start the
    // scan to run for 5 seconds.
    BLEScan *pBLEScan = BLEDevice::getScan();
    pBLEScan->setAdvertisedDeviceCallbacks(new MyAdvertisedDeviceCallbacks());
    pBLEScan->setInterval(1349);
    pBLEScan->setWindow(449);
    pBLEScan->setActiveScan(true);
    pBLEScan->start(5, false);
} // End of setup.
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

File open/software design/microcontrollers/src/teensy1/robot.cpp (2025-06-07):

#include "main.h"
#include <iostream>
#include <cmath>
#include <vector>
#include <algorithm>

bool raffles_goalie = false;

const double STEP_SIZE = 100.0; // Set step size to 10

// Function f(x) = -5 * 10^-15 * x^6 - 700
double f(double x)
{
    return -5e-15 * pow(x, 6) - 500;
}

// First derivative of f(x)
double df(double x)
{
    return -30e-15 * pow(x, 5);
}

// Second derivative of f(x)
double d2f(double x)
{
    return -150e-15 * pow(x, 4);
}

struct Point
{
    double x, y;
};

// Compute Euclidean distance between two points
double distance(Point a, Point b)
{
    return sqrt(pow(a.x - b.x, 2) + pow(a.y - b.y, 2));
}

// Find the next point toward the target with a limited step size
Point findNextPoint(Point current, Point target, double step_size)
{
    // Ensure current is on the graph
    current.y = f(current.x);

    // Compute gradient direction
    double slope = df(current.x);
    double dx = step_size / sqrt(1 + slope * slope);
    dx = (target.x > current.x) ? dx : -dx; // Move toward target

    double max_dx = fabs(target.x - current.x); // Limit dx to not exceed error
    if (fabs(dx) > max_dx)
    {
        dx = (dx > 0) ? max_dx : -max_dx;
    }

    double new_x = current.x + dx;
    double new_y = f(new_x);

    return {new_x, new_y};
}

// Newton's Method to find the closest x on the curve
double findClosestX(double x0, double y0, double x_init, int max_iter = 50, double tol = 1e-6)
{
    double x = x_init;
    for (int i = 0; i < max_iter; i++)
    {
        double y = f(x);
        double dy_dx = df(x);
        double d2y_dx2 = d2f(x);

        double grad = 2 * (x - x0) + 2 * (y - y0) * dy_dx;
        double hessian = 2 + 2 * pow(dy_dx, 2) + 2 * (y - y0) * d2y_dx2;

        if (fabs(grad) < tol)
            break; // Stop if gradient is small

        x -= grad / hessian; // Newton update step
    }
    return x;
}

double prev_distance = 0;
double previous_error = 0;
// double previous_

void Robot::moveToPoint(double x, double y, double bearing, double min_speed = 0.15, double max_speed = 0.35)
{
    double kp = 0.00045;

    double target_x = x - robot.current_pose.x;
    double target_y = y - robot.current_pose.y;
    // Serial.println("target x: " + String(target_x) + " target y: " + String(target_y));
    double distance = sqrt(pow(target_x, 2) + pow(target_y, 2));

    double speed = bound(kp * distance, min_speed, max_speed);

    move_data.speed = (distance == 0) ? 0 : speed;
    move_data.target_angle = xyToBearing(target_x, target_y);
    // Serial.println("target angle: " + String(move_data.target_angle));
    move_data.target_bearing = bearing;
    // move_data.ema_constant = 0.0002;
    prev_distance = distance;
}

void Robot::goalieTrack()
{
    // TUNE THIS
    double min_speed = 0.1;
    if (robot.current_pose.y > -500)
    {
        min_speed = 0.2;
    }

    double max_speed = 0.45;
    // double decel_f = 40;
    // double decel_k = 0.08;

    double Kp = 0.001;
    double Ki = 0;
    double Kd = 0.00001; // PID coefficients
    // END TUNE

    double distance = sqrt(pow(ball.current_pose.x, 2) + pow(ball.current_pose.y, 2));
    double target_x, target_y;
    double target_angle, target_bearing;

    Point current_pos, target_pos;

    current_pos.x = findClosestX(robot.current_pose.x, robot.current_pose.y, robot.current_pose.x);
    current_pos.y = f(current_pos.x);

    if (ball.detected)
    {
        target_pos.x = findClosestX(ball.current_pose.x + robot.current_pose.x, ball.current_pose.y + robot.current_pose.y, ball.current_pose.x + robot.current_pose.x);
        target_pos.y = f(target_pose.x);
    }
    else
    {
        
        if (raffles_goalie)
        {
            if (ball.ball_last_seen.x > 0)
            {
                target_pos.x = 500;
            }
            else
            {
                target_pos.x = -500;
            }
            target_pos.y = f(target_pos.x);
        } else {
            target_pos.x = 0;
            target_pos.y = f(target_pos.x);
        }
    }

    double angle = ball.current_pose.bearing;

    if (angle > 180)
    {
        angle -= 360;
        angle = abs(angle);
    }

    if (angle > 90)
    {
        angle -= 180;
        angle = abs(angle);
    }

    double step_mutli = 1;

    if (angle > 35)
    {
        step_mutli = 3;
    }

    // Serial.print("angle: " + String(angle) + " error: " + String(error) + " speed: " + String(speed));

    Point result;
    result = findNextPoint(current_pos, target_pos, step_mutli * STEP_SIZE);

    double error = bound((15 * exp(0.2 * angle - 5)) + 4 * angle + 20 / abs(ball.current_pose.y), 0, 300);

    // Proportional term
    double proportional = Kp * error;

    // Derivative term
    double derivative = Kd * (error - previous_error);

    // Store the current error for the next iteration
    previous_error = error;

    // PID output is the sum of the proportional, integral, and derivative terms
    Serial.println("result: " + String(result.y));
    if (result.y < -700)
    {
        max_speed = 0.2;
    }

    double edge_a = 3.4;
    double edge_b = 0.007;
    double edge_c = 0.0;
    double edge_d = 0.2;

    double average_goal_x;

    if (yellow_goal.detected && blue_goal.detected)
    {
        average_goal_x = abs((yellow_goal.current_pose.x + blue_goal.current_pose.x) / 2);
    }
    else if (yellow_goal.detected)
    {
        average_goal_x = abs(yellow_goal.current_pose.x);
    }
    else if (blue_goal.detected)
    {
        average_goal_x = abs(blue_goal.current_pose.x);
    }
    else
    {
        average_goal_x = 0;
    }

    double max_speed_scaled = fmin(edge_a * exp((-edge_b * average_goal_x) + edge_c) + edge_d, max_speed);

    double speed = bound(proportional + derivative, min_speed, max_speed_scaled);

    if (!ball.detected)
    {
        robot.moveToPoint(result.x, bound(result.y, -1100, 0), 0, 0.15, 0.3);
    } else {
        robot.moveToPoint(result.x, bound(result.y, -1100, 0), 0, speed, speed);
    }
}

void Robot::goalieRush()
{
    double angle = ball.current_pose.bearing;

    if (angle > 180)
    {
        angle -= 360;
        angle = abs(angle);
    }

    double min_speed;
    if (ball.in_catchment)
    {
        min_speed = 0.4;
    }
    else
    {
        min_speed = 0.35;
    }

    robot.moveToPoint(ball.current_pose.x + robot.current_pose.x, ball.current_pose.y + robot.current_pose.y - bound(angle / 5 * 70, 0, 300), 0, min_speed, 0.5);
}
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

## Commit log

2024-10-29 rename folder lw 2024
    [ir.kicad_sch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]
2024-10-29 rename dir
    [ir.kicad_sch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]
2024-12-31 mech design stuff
    [battery guide wall.stl, cover (layer 2).stl, cover back (layer 1).stl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]
2025-01-07 screw drawing
    [cover back (layer 1).3mf, cover front (layer 1).3mf, cover left (layer 1).3mf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]
2025-01-08 my balls itch daddy
    [moldnigger_cap.3mf, moldnigger_left_right_front_back.3mf]
2025-01-11 moved ducc shirt assets to branding repo
    [25-09-01.3mf, cover (layer 2).3mf, cover (layer 2).stl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]
2025-02-01 edit folder names
    [battery guide wall.3mf, cam1.kicad_sch, cm4 mount.stl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]
2025-02-01 patch missing software files
    [base.cpp, main.cpp]
2025-02-01 some 3mf files and switcherboard schema
    [cam3switcher.kicad_pcb, cam3switcher.kicad_sch, left plate.3mf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]
2025-02-01 minor changes to switcher board
    [cam3switcher.kicad_pcb, cam3switcher.kicad_sch]
2025-02-01 switcher board router i2c of camera to csi i2c lanes
    [cam3switcher.kicad_pcb, cam3switcher.kicad_sch, cover right (layer 1).3mf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]
2025-02-07 service files, changed raspi-gpio to pinctrl in configure gpio service for cm5, as raspi-gpio is no longer supported; disabled show debug windows in threads.h
2025-02-15 removed all references of Lidar
2025-02-21 Add new 3D models and remove obsolete files from mechanical design
    [buck support.3mf, layer 1 anti-short.3mf, master.3mf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]
2025-02-25 try to fix local, dk if works @isaac
    [camera.cpp, serial.cpp]
2025-02-25 issue: regression for goals are ass
    [camera.cpp, serial.cpp]
2025-02-26 Add debugging output for yellow and blue goal positions in camera pose TODO: check threshold again
2025-02-27 Update mechanical design files, new mirror drawings
    [master.3mf, mirror v7.step, rpi mount base a lower.3mf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]
2025-02-27 layer 4 dxf new
    [layer 4.dxf]
2025-02-27 some mech stuff
    [layer 4.dxf, roller.3mf, wheel.3mf]
2025-02-28 Update master.3mf file in mechanical design
    [master.3mf]
2025-02-28 regression new algo
    [layer 4.dxf, master.3mf, roller.3mf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]
2025-03-03 mech stuff
    [cover front (layer 1).3mf, master.3mf, roller.3mf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]
2025-03-03 remove lidar reference
2025-03-03 comment out debug print statements in algorithm and serial files
2025-03-03 im gonna lose it why tf does imu serial not work
    [main.cpp, main.h, serial.cpp]
2025-03-03 update 3D model files for mechanical design
    [master.3mf, rpi mount base a upper.3mf]
2025-03-04 get IMU to send serial (temporary fix)
    [main.cpp]
2025-03-04 add payload size validation and improve error logging in serial handling
    [serial.cpp]
2025-03-04 remove unused lidar functions and improve payload size validation in serial handling
2025-03-05 enhance error logging for invalid payload size in serial handling
    [serial.cpp]
2025-03-05 improve error logging for invalid payload size in serial handling
    [serial.cpp]
2025-03-05 fix: reduce camera serial baud rate to 500k
    [serial.h]
2025-03-05 fix: enhance error logging for invalid payload sizes in IMU and Teensy data handling
    [serial.cpp]
2025-03-05 remove lidar refs
2025-03-05 fix: update camera serial baud rate comment for clarity
    [serial.h]
2025-03-06 fix: correct logging statement for IMU bearing data and add todo comment for serial condition
    [serial.cpp]
2025-03-06 feat: add new DXF file for mechanical design layer 4 and 5
    [layer 4 (new).dxf, layer 5.dxf]
2025-03-06 fix lower camera baudrate to 500k (l1 to teensy1 works now)
    [serial.h]
2025-03-07 refactor serial communication settings and improve debug output for camera data
2025-03-07 increase teensy1 serial baud rate from 1M to 2M for improved communication
2025-03-07 moved camera serial receiving to teensy1
2025-03-09 add new DXF file for layer 5.1 and update layer 5
    [layer 5.1.dxf, master.3mf]
2025-03-10 update nut hole tester design file
    [nut hole tester.3mf]
2025-03-10 update light ring thresholds, calibrate bot b threshold for lighring
2025-03-10 Revert to commit 2434547
    [nut hole tester.3mf]
2025-03-12 Update light ring thresholds, adjust ball threshold, and enhance camera pose calculations
2025-03-12 Replace orbitToBall call with striker function in main loop
    [main.cpp]
2025-03-12 bunch of mech changes
    [layer 4 (new).dxf, layer 4.dxf, layer 5.1.dxf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]
2025-03-12 Replace min with fmin for velocity and angular velocity clamping
    [base.cpp]
2025-03-13 added x-axis threshold to prevent stalling when bot thinks ball is in goal but its not (still need to test)
    [camera.cpp]
2025-03-14 update cover front design in layer 1
    [cover front (layer 1).3mf]
2025-03-14 use millis to set timer
2025-03-14 update mechanical design file with new specifications
    [master.3mf]
2025-03-16 update catchment area cover
    [cover front (layer 1).3mf, master.3mf]
2025-03-16 fix: correct bearing calculation in xyToBearing function
2025-03-16 goalie track ball x
2025-03-16 fix: adjust ball threshold
    [main.cpp, main.h]
2025-03-16 fix striker code not working (goal y was declared outside of functions and does not get updated)
    [main.cpp]
2025-03-17 fix: reduce catchment timeout and improve striker task handling
    [main.cpp]
2025-03-17 feat: add new kicker slide design and update existing mechanical components
    [master.3mf, rack.3mf, slide.3mf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]
2025-03-17 added back payload size check from cam to teensy1
2025-03-17 feat: update mechanical design files for kicker components
    [Spur Gear (12 teeth).3mf, master.3mf, rack.3mf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]
2025-03-18 feat: refactor camera pose handling and update method names for clarity
2025-03-18 feat: add methods to store open goal poses and update camera pose handling
2025-03-18 feat: rename camera pose methods to goal pose for consistency
2025-03-19 revert to xyToBearing function and update target_angle calculations
    [robot.cpp]
2025-03-19 kicker stuff
    [Spur Gear (12 teeth).3mf, gear rack.3mf, rack.3mf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]
2025-03-19 chore: update mechanical design files for kicker components
    [Spur Gear (12 teeth).3mf, gear rack.3mf, ratchet gear mount.3mf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]
2025-03-21 tune: adjust goalie tracking parameters and implement PID control for speed
2025-03-22 many mech changes
    [Spur Gear (12 teeth) 2.3mf, Spur Gear (12 teeth).3mf, cover front (layer 1).3mf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]
2025-03-25 update: modify spur gear and master design files
    [Spur Gear (12 teeth).3mf]
2025-03-27 mech stuffs
    [cover (layer 3).3mf]
2025-03-28 fix serial and regression for orbit
    [main.cpp, serial.cpp, serial.h]
2025-03-28 introduce autosave functionality for calibration
2025-03-29 tune calibration values
2025-03-29 big load of mech stuff baby
    [Spur Gear (12 teeth).3mf, buck cover left.3mf, buck cover right.3mf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]
2025-03-31 remove getNewImage from threading
2025-03-31 revert to old code, convert to 450x450 frame
2025-04-01 mech new kicker
    [cover (layer 3).3mf, gear holder.3mf, gear.3mf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]
2025-04-04 Enable debug mode and adjust ball threshold; refactor kicker servo logic for improved timing and control

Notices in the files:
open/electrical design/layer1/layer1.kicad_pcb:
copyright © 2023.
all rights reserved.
